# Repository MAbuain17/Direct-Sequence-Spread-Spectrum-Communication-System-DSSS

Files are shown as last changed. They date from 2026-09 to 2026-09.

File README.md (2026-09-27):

# DSSS Lab

**Configurable spread-spectrum hardware, receiver experiments and a multiuser CDMA study.**




The project combines a 2 MHz bench implementation with a configurable I/Q board design. Rev A integrates an STM32G474, dual DAC outputs, receive inputs and digital expansion around a programmable signal chain.

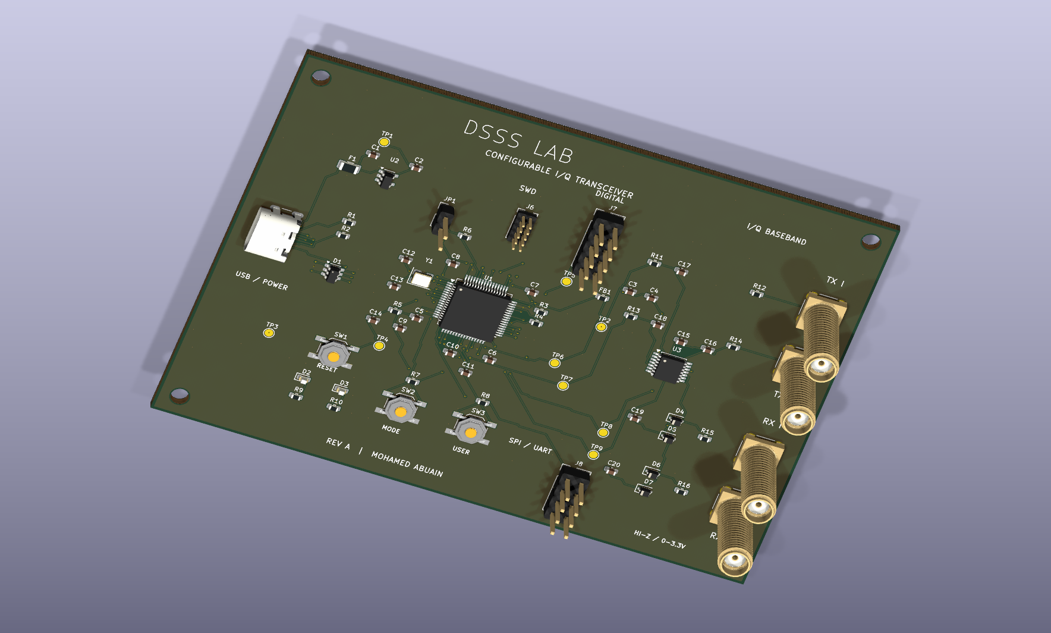
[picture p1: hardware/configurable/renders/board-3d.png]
Configurable DSSS transceiver PCB


## Configurable hardware — Rev A

| Area | Design |
|---|---|
| Data | User bits, text, hexadecimal payloads, PRBS and repeating patterns |
| Spreading | Selectable LFSR taps, seed, code phase and spreading length; uploaded sequences |
| Modulation | BPSK, QPSK, OOK and continuous-phase 2-FSK in the firmware specification |
| Analogue | Buffered TX I/Q, filtered and protected RX I/Q, four labelled SMA ports |
| Control | USB-C, reset/mode/user buttons, status LEDs and test points |
| Development | SWD/SWO programming, SPI/UART expansion, chip/data/PN/frame signals |
| PCB | 110 × 80 mm, four copper layers, routed nets, ground planes and M3 mounting holes |

The [hardware package](hardware/configurable/README.md) includes the schematic, routed PCB, board renders, component list and control interface.

## Explore the project

| Topic | Open |
|---|---|
| PCB architecture, BOM and renders | [Configurable hardware](hardware/configurable/README.md) |
| Signal modes and USB commands | [Control interface](hardware/configurable/control-interface.md) |
| Original bench build and captures | [Laboratory implementation](hardware/README.md) |
| BER, interference and synchronization | [Simulation results](docs/results.md) |
| Multiuser access, near–far and receiver algorithms | [CDMA extension](docs/cdma.md) |
| Interactive code and receiver study | [CDMA signal explorer](visualizer/index.html) |
| Signal-chain conventions and parameters | [Methodology](docs/methodology.md) |
| Python, MATLAB and Octave setup | [Getting started](docs/getting-started.md) |

## Run Python

From the repository root, using Python 3.10 or later:

```bash
python -m pip install -e .
python -m unittest discover -s tests -v
python examples/burst_link.py
python -m dsss_lab.experiments
python examples/pulse_shaping.py
python examples/cdma_study.py
```

For a smaller run, add `--quick` to the experiment command. CSV files, figures and environment metadata are written to `results/`. Running without installing is also possible with `PYTHONPATH=src` on Linux/macOS; see the Windows guide for PowerShell.

## Run MATLAB

No Communications Toolbox is required. From the repository root:

```matlab
addpath('matlab');
test_dsss;
run_experiments('results/matlab', 12000);
advanced_demo('results/matlab');
```

MATLAB shares deterministic test vectors with Python. Random-number streams differ, so Monte Carlo results should agree statistically, not bit-for-bit. **Python, GNU Octave and native MATLAB pass the published GitHub Actions validation workflows.** Native MATLAB runs automatically when its implementation, shared vectors or workflow changes and remains manually dispatchable.

## What the software explores

| Area | Implemented experiments |
|---|---|
| Data | Random bits, constants, alternating patterns, bursts, UTF-8 text, 8-bit PCM, CRC32 frames |
| Spreading | Exact hardware XNOR recurrence, code phase, autocorrelation, configurable spreading length, two-user Gold-family interference |
| Channels | AWGN; in-band and out-of-band tones; swept interference; burst noise; multipath; symbol-independent Rayleigh fading |
| Receiver | Coherent despreading, known-preamble delay/CFO acquisition, burst phase correction, known-channel matched combining |
| Front end | Carrier offset, phase offset/noise, fractional timing error, ADC clipping/quantization, IQ imbalance, RRC pulse shaping |
| Measurements | BER with Wilson intervals, frame CRC failure rate, acquisition success, raw decision EVM, Welch PSD and 99% occupied bandwidth |
| Coding | Soft repetition decoding with equal information-bit energy as a normalization check |

## BER and interference

DSSS and BPSK BER against theory

At equal information-bit energy, DSSS and ordinary coherent BPSK have the same theoretical BER in AWGN. Spreading's interference behaviour depends on the interferer's spectrum and the receiver. The experiments include cases where DSSS helps and cases where the narrower unspread receiver performs better.

Interference comparison

The simulation uses 60,000 bits per AWGN point and 30,000 bits per interference point. Source CSVs include error counts and confidence intervals; seeds and model settings are documented in [methodology](docs/methodology.md).

## From DSSS to CDMA

The [CDMA extension](docs/cdma.md) combines four spread-spectrum users in one channel and compares a matched filter, decorrelator and linear MMSE receiver under code-phase and near–far changes. The sweep records 45 conditions with 12,000 desired-user bits each. A separate [browser explorer](visualizer/index.html) exposes the code correlations, chip waveforms and receiver decisions interactively.

To use the explorer, download or clone the repository and open `visualizer/index.html` in a browser.

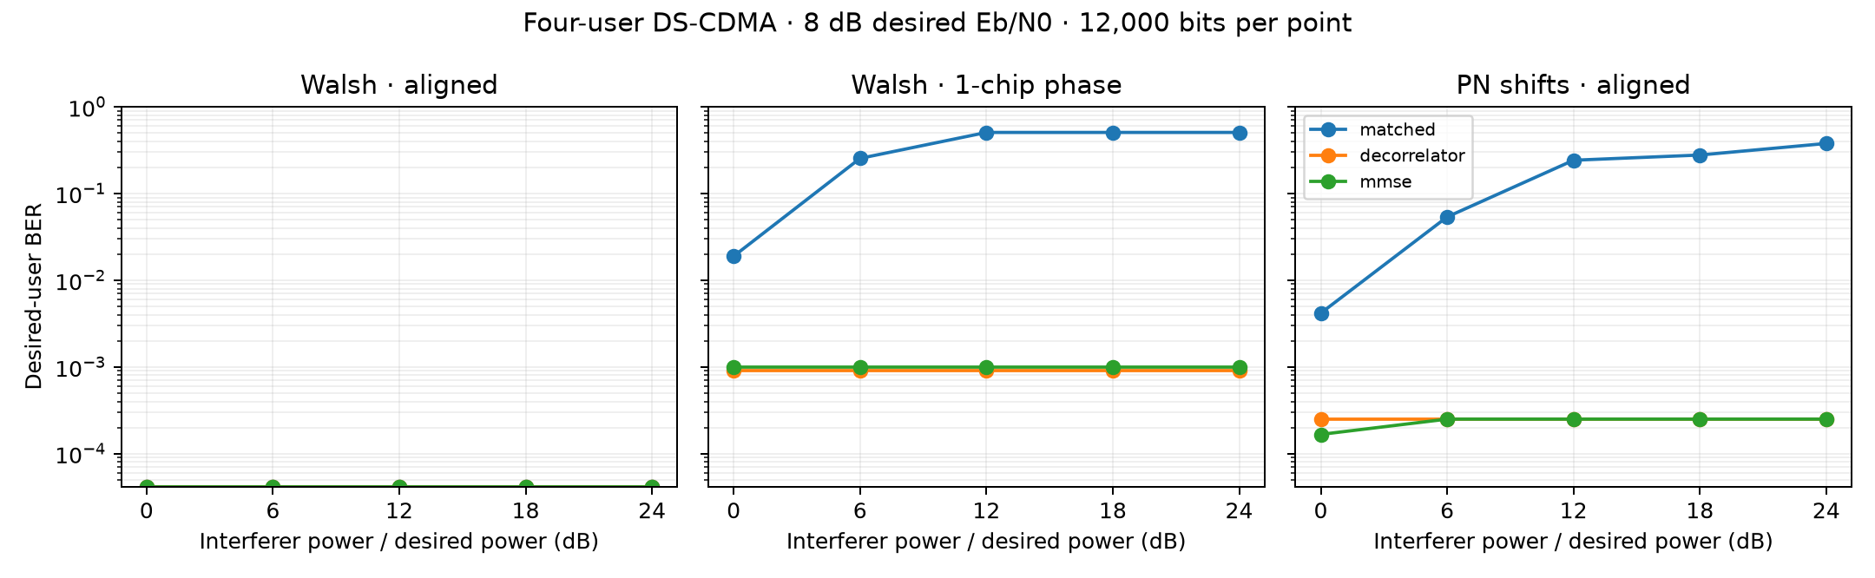
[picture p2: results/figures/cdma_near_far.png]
Four-user CDMA receiver comparison


## Credits

Project by **Mohamed Abuain**. The university bench implementation was supervised by Prof. Tammam Benmusa. Its circuit reference and source article are recorded in the [design references](docs/attribution.md).

[Software licence](LICENSE.md) · [Changelog](CHANGELOG.md) · [Roadmap](docs/roadmap.md)

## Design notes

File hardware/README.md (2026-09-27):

# Laboratory implementation

The original 2 MHz university bench project by Mohamed Abuain. The new [configurable Rev A board](configurable/README.md) adds a programmable signal chain and I/Q interfaces.

Breadboard assembly

The transmitter and receiver use PN generators, XOR spreading, square-carrier BPSK, comparator-driven code acquisition, a latch and clock switch, and an LM/MC1496 balanced demodulator. The laboratory setup uses a shared reference and a wired connection between transmitter and receiver.

## Circuit files

| File | Description |
|---|---|
| [DSSS_MAbuain.ms14](original/DSSS_MAbuain.ms14) | Main Multisim 14 project |
| [GOLD1.ms14](original/GOLD1.ms14) | Additional Multisim project |
| [MC1496_split_Gilbert_Cell_Test.asc](original/MC1496_split_Gilbert_Cell_Test.asc) | LTspice balanced-demodulator test schematic |
| `original/dsss.kicad_*` | Original KiCad layout concept |
| [Laboratory report](../docs/original-report.pdf) | Circuit description, measurements and discussion |

The [Rev A PCB package](configurable/README.md) contains the programmable baseband design, routed board and renders. [Engineering notes](../docs/errata.md) explain the original clock and spreading conventions.

## Laboratory captures

| Capture | Description |
|---|---|
| [Lab setup](../assets/lab-15.jpg) | Breadboard connected to test equipment |
| [Board close-up](../assets/lab-20.jpg) | Component placement and wiring |
| [Logic waveforms](../assets/lab-11.jpg) | Oscilloscope capture of digital signals |
| [Spectrum](../assets/lab-14.jpg) | Spectrum-analyzer capture |
| [Recovered signal](../assets/lab-01.jpg) | Demodulated waveform |

The report provides the context for these captures. Numerical BER and channel studies are documented in [simulation results](../docs/results.md).

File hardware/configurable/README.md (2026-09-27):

# Configurable DSSS transceiver — Rev A

Rev A PCB

A USB-controlled I/Q baseband board built around the STM32G474RET6. The architecture replaces fixed logic with programmable data generation, spreading and symbol mapping, while exposing both analogue channels and digital timing signals for measurement.

**Design:** 110 × 80 mm · four copper layers · 70 circuit components · four SMA ports · USB-C · SWD · SPI/UART expansion.

## Configurable signal chain

```mermaid
flowchart LR
    H[USB host: payload and configuration] --> P[Payload / preamble / CRC]
    P --> S[Programmable spreading]
    N[LFSR taps, seed, length and phase] --> S
    S --> M[BPSK / QPSK / OOK / 2-FSK mapping]
    M --> D[Timer-triggered dual DAC + DMA]
    D --> T[RC filters + I/Q buffers]
    T --> O[TX I / TX Q]
    I[RX I / RX Q] --> A[Input resistors, clamps and RC filters]
    A --> B[Receive buffers + dual ADC]
    B --> R[DMA capture / host analysis]
    S --> G[Chip clock / data / PN / frame header]
```

## Planned operating controls

| Control | Options |
|---|---|
| Payload | User bit string, hexadecimal bytes, UTF-8 text, PRBS, alternating bits, all-zero/all-one and repeating patterns |
| PN sequence | Configurable Fibonacci LFSR order, feedback taps, seed, code phase and spreading length; optional uploaded chip sequence |
| Modulation | BPSK, Gray-mapped QPSK, OOK and continuous-phase 2-FSK |
| Timing | Chip rate, samples per chip, burst duration, frame spacing and repeat count |
| Framing | Preamble, length, payload and CRC32; raw chip mode for scope captures |
| Experiments | I/Q loopback, code mismatch, delay sweeps, burst acquisition and known-pattern BER comparisons |
| Instrumentation | Digital chip clock, data, PN and frame signals; DAC/ADC test pads; status LEDs |

Rev A includes the schematic, routed PCB and control specification. Firmware and board bring-up are the next development stage. The Python/MATLAB simulations remain available for numerical experiments.

## Hardware blocks

| Block | Implementation |
|---|---|
| Processing | STM32G474RET6, LQFP64; Cortex-M4 with hardware timers, DMA, dual DAC and multiple ADCs |
| USB | GCT USB4105 USB-C connector, separate 5.1 kΩ CC pull-downs, USBLC6 protection and 22 Ω data-line resistors |
| Power | USB 5 V, 500 mA PTC, AP2112K 3.3 V regulator; ferrite-filtered analogue rail and local decoupling |
| Clock | 8 MHz crystal with load capacitors; USB clock configuration described in the firmware plan |
| Transmit | PA4/PA5 DAC outputs, 1 kΩ / 1 nF RC filters, TLV9064 unity-gain buffers and 100 Ω output isolation |
| Receive | Series input resistance, Schottky clamps, 1 kΩ / 1 nF RC filtering, TLV9064 buffers and PC0/PC1 ADC inputs |
| Development | SWD/SWO, reset button, boot jumper, mode/user buttons, TX/RX LEDs and SPI/UART header |
| Mechanical | Four M3 mounting holes, separated USB/power, processing and analogue regions, labelled SMA ports |

The SMA connections carry **DC-biased baseband I/Q**, with high-impedance loading. They are not antenna outputs or 50 Ω line drivers. The default development target is 25 kchip/s at four samples/chip; the analogue RC corner is approximately 159 kHz. Rate limits depend on firmware timing, conversion settings and filter response.

## Design files

| File | Contents |
|---|---|
| [KiCad project](dsss-configurable.kicad_pro) | Board rules and project settings |
| [Schematic](dsss-configurable.kicad_sch) | Connected component-level design |
| [PCB](dsss-configurable.kicad_pcb) | Four-layer layout, copper tracks, vias and filled ground planes |
| [Local symbol library](dsss-configurable.kicad_sym) | Embedded component symbols for the project |
| [Schematic preview](renders/schematic.svg) | Browser-readable circuit drawing |
| [Top view](renders/board-top.png) | Component placement and silkscreen |
| [Copper view](renders/copper.svg) | Routed layout |
| [Bill of materials](bom.csv) | References, values and footprints |
| [Pin map](pin-map.md) | MCU peripheral and connector assignments |
| [Control interface](control-interface.md) | Proposed USB commands, modes and frame format |
| [Design review](design-review.md) | Connectivity checks and next review items |

Open `dsss-configurable.kicad_pro` in KiCad 10. The standard footprint and 3D model libraries supply the component geometry; the local symbol library is included in the project.

## Component references

- [ST STM32G474RE datasheet](https://www.st.com/resource/en/datasheet/stm32g474re.pdf)
- [TI TLV9064](https://www.ti.com/product/TLV9064)
- [Diodes AP2112 datasheet](https://www.diodes.com/datasheet/download/AP2112.pdf)

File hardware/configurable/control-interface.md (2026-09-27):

# USB control and firmware plan

This document specifies the Rev A firmware interface. It is a design specification; no flashed-board execution is recorded.

## Commands

USB CDC carries one JSON command per line. Replies include the command name, success/error status and the active configuration. The board starts idle after reset and applies configuration changes between bursts.

| Command | Purpose |
|---|---|
| `configure` | Set modulation, chip rate, samples/chip, spreading length and amplitude |
| `pn` | Set LFSR order, taps, nonzero seed and phase, or upload a custom binary chip sequence |
| `payload` | Upload a bit string, hexadecimal bytes or UTF-8 text; select a repeating test pattern |
| `frame` | Set preamble, CRC, repeat count and inter-frame gap |
| `tx` | Start or stop transmission; report samples and frames sent |
| `capture` | Return a bounded dual-ADC capture with sample rate and channel metadata |
| `status` | Return configuration, DMA underruns/overruns and frame counters |
| `loopback` | Compare a known transmitted pattern with captured I/Q after host synchronization |

Example configuration:

```json
{"command":"configure","modulation":"qpsk","chip_rate_hz":25000,"samples_per_chip":4,"spreading_length":127,"amplitude":0.6}
{"command":"pn","order":7,"taps":[7,6],"seed":1,"phase":0}
{"command":"payload","encoding":"bits","data":"1011001010110001"}
{"command":"tx","action":"start","frames":100}
```

The taps use polynomial exponents: `[7,6]` represents x⁷ + x⁶ + 1. Firmware must define the shift direction and output stage, and publish sequence vectors before comparing this mode with the existing inverted-feedback model. Arbitrary taps can produce short cycles; only verified maximal polynomials should be labelled PRBS.

## Modes

| Mode | Mapping | I/Q outputs |
|---|---|---|
| BPSK | Chip 0 → +1; chip 1 → −1 | I carries the bipolar chip waveform; Q stays at the bias level |
| QPSK | Gray mapping: 00 → (+,+), 01 → (+,−), 11 → (−,−), 10 → (−,+), normalized by √2 | Consecutive spread-chip pairs drive I and Q |
| OOK | Chip 0 → off; chip 1 → on | I carries the unipolar waveform; Q stays at bias |
| 2-FSK | Chip chooses f₀ or f₁; phase accumulator continues across chip boundaries | I/Q carry the complex baseband oscillator |

Digital symbols are converted to unsigned DAC samples around a mid-supply bias. Requested amplitude must leave buffer and DAC headroom. Chip rate counts spread chips before QPSK pairing; QPSK symbol rate is half the chip rate. An odd chip count is padded explicitly and its original length retained.

## Frame format

`preamble | payload length | payload | CRC32`

The preamble, length endianness and CRC polynomial/initialization belong in shared golden vectors. Raw mode bypasses framing for continuous code and logic measurements. A repeating payload is useful for eye diagrams; a PRBS payload is useful for error-rate tests.

## Firmware structure

1. Configure clocks, USB CDC, SWD, GPIO and the analogue peripherals. Use HSI48 with USB SOF clock recovery for USB; configure the HSE/PLL separately for processing and timers.
2. Generate payload bits, PN chips and mapped symbols into bounded ping-pong buffers. Use DMA to stream packed dual-DAC samples under a shared timer trigger.
3. Configure ADC1/ADC2 with simultaneous sampling, timer triggering and DMA. Confirm trigger routing and sampling-time settings against the STM32G4 reference manual.
4. Use the digital header for chip/data/PN/frame observations. Keep the GPIO waveform schedule synchronized with the sample timer.
5. Detect underruns and overruns, stop cleanly on error, and apply configuration changes at buffer or frame boundaries.
6. Implement a host receiver for correlation, code-phase search, symbol decisions and CRC/BER comparison. Later move selected receiver stages onto the MCU after profiling.

Initial analogue target: 25 kchip/s, four samples/chip, 100 ksample/s per DAC channel. Buffer memory, USB throughput, ADC capture bandwidth and interrupt load determine higher-rate operation.

## Useful extensions

- Uploaded PN sequences and Gold-code pairs for code-division experiments.
- Adjustable gain/phase mismatch in the transmitted I/Q waveform.
- Repeated frames with controlled code phase for acquisition sweeps.
- SPI-connected display, RF conversion module or programmable attenuator.
- Code and modulation profiles stored in flash with a configuration checksum.

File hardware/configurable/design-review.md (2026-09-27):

# Rev A design review

## CAD checks

KiCad 10.0.6 checks on 27 September 2026:

| Check | Result |
|---|---|
| Schematic ERC | 0 violations |
| PCB DRC | 0 violations |
| Unconnected PCB items | 0 |
| Layout | Four copper layers; 110 × 80 mm |
| Circuit components / nets | 70 / 48 |

The schematic and PCB use the same component pin map. The USB connector shell is grounded, unused MCU pins are marked unconnected, and the inner ground plane connects the analogue and digital return paths. Local ground pours also cover the outer copper layers.

Default signal clearance is 0.15 mm. Escape vias use 0.45 mm pads and 0.20 mm drills. The USB-C footprint has a specific 0.18 mm pad-to-locating-hole clearance rule to accommodate its standard library geometry; confirm that geometry and tolerances with the board supplier.

Machine-readable counts are recorded in [design-checks.json](design-checks.json).

## Engineering review before a prototype

- Confirm the ordered MCU, regulator, USB connector, crystal and SMA part numbers against their footprints and data sheets.
- Review USB D+/D− routing, return continuity and signal integrity at full-speed USB; the existing traces are connected but do not constitute an impedance-controlled transmission-line specification.
- Check USB current budget, AP2112 thermal dissipation, PTC hold current, ferrite current rating and analogue-rail noise.
- Confirm the crystal load and drive settings. The 15 pF capacitor choice assumes approximately 2.5 pF total stray capacitance for a 10 pF load target; adjust for the selected crystal and board.
- Check DAC output headroom, buffer stability, input clamp leakage and the RC response at each intended sample/chip rate.
- Verify boot/reset options, USB clock recovery, timer trigger selection, dual-ADC sampling and DMA buffer timing in firmware.
- Review layer stack-up, minimum drill capability, annular rings, assembly access and connector mechanical fit with the manufacturer.

## Development stage

Rev A is a connected schematic and routed PCB design. Firmware implementation, fabrication and physical measurements are subsequent milestones. The existing laboratory photographs document the earlier bench implementation.

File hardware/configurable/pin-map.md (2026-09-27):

# Pin map

## STM32G474RET6 — LQFP64

| Function | Pin / port | Board net |
|---|---|---|
| TX I | 18 / PA4, DAC1_OUT1 | DAC_I |
| TX Q | 19 / PA5, DAC1_OUT2 | DAC_Q |
| RX I | 8 / PC0, ADC1_IN6 | ADC_I |
| RX Q | 9 / PC1, ADC2_IN7 | ADC_Q |
| USB D− / D+ | 45 / PA11, 46 / PA12 | USB_DM_MCU / USB_DP_MCU |
| HSE crystal | 5 / PF0, 6 / PF1 | HSE_IN / HSE_OUT |
| Reset | 7 / PG10-NRST | NRST |
| Debug | 49 / PA13, 50 / PA14, 56 / PB3 | SWDIO / SWCLK / SWO |
| Chip clock | 42 / PA8 | CHIP_CLK |
| Data / PN | 59 / PB6, 60 / PB7 | DATA_OUT / PN_OUT |
| Frame marker | 38 / PC6 | FRAME |
| SPI2 | 34 / PB12, 35 / PB13, 36 / PB14, 37 / PB15 | SPI_CS / SPI_SCK / SPI_MISO / SPI_MOSI |
| USART2 | 14 / PA2, 17 / PA3 | UART_TX / UART_RX |
| Buttons | 2 / PC13, 3 / PC14 | BTN_MODE / BTN_USER |
| Indicators | 24 / PB0, 25 / PB1 | LED_TX / LED_RX |
| Boot selection | 61 / PB8-BOOT0 | BOOT0 |

The pin assignments are based on the [ST datasheet](https://www.st.com/resource/en/datasheet/stm32g474re.pdf). Firmware must configure alternate functions and the boot option bytes for the selected usage.

## Connectors

| Connector | Odd pins | Even pins |
|---|---|---|
| J6 SWD, 2 × 5 at 1.27 mm | 1: 3.3 V; 3: GND; 5: GND; 7: unused; 9: GND | 2: SWDIO; 4: SWCLK; 6: SWO; 8: unused; 10: NRST |
| J7 digital, 2 × 5 at 2.54 mm | 1: 3.3 V; 3: chip clock; 5: data; 7: PN; 9: frame | Ground on all even pins |
| J8 expansion, 2 × 4 at 2.54 mm | 1: 3.3 V; 3: SPI CS; 5: MOSI; 7: UART TX | 2: GND; 4: SPI SCK; 6: MISO; 8: UART RX |

J2/J3 are TX I/Q; J4/J5 are RX I/Q. All SMA shells connect to ground. JP1 connects BOOT0 to 3.3 V; R6 holds it low with the jumper removed.

All digital expansion signals use 3.3 V logic. The USB port is the board's power input.

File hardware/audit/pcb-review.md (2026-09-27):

# PCB review and layout plan

The KiCad files contain a component placement study with routing pending. The structural audit records 169 footprints, 532 pads, 112 pads assigned a nonzero net, 26 declared nets, two zones, zero track segments, and zero vias. The supplied schematic contains 10 placed symbols and zero wires. These counts are reproduced by `python tools/audit_kicad.py` and recorded in `structural-audit.json`.

ERC and DRC are pending completion of the connected schematic and board layout.

## Electrical issues to resolve before layout

| Area | Required work | Acceptance evidence |
|---|---|---|
| Source of truth | Export the as-built Multisim netlist and compare it with the report and QEX schematic | Pin-by-pin reviewed netlist and reconciled BOM |
| Logic families | Audit LS outputs into HC and 4000-series CMOS, including the comparator | Worst-case VOH/VOL versus VIH/VIL and fanout worksheet; validated substitutions |
| PN generator | Confirm QA/QG taps, inversion, reset, unused eighth output and feedback pin assignment | 127-state capture and reset test |
| Clock doubler | Check RC timing, pulse widths, hysteresis and frequency over supply/tolerance | Minimum high/low pulse margins for the selected receiving IC |
| Clock switching | Check CD4066 pulse integrity and avoid runt pulses while switching 4/2 MHz | Clock capture through acquisition and repeated resets |
| Comparator/latch | Confirm unused comparator input pair, enable pin, polarity and startup state | Deliberately varied initial code phases and verified lock |
| Demodulator | Validate exact MC/LM1496 manufacturer pinout, bias, input attenuation and load | DC operating points, gain and clipping measurements |
| Power | Separate labelled +5 V logic and +12 V analogue inputs with common reference | Current limits, local decoupling, startup/reset behaviour |
| Output conditioning | Design/verify low-pass filtering and logic threshold recovery | Recovered waveform, duty distortion and BER under a defined test |
| Testability | Add labelled probes for reference, carrier, TX PN, RX PN, spread data, lock and recovered data | Accessible ground-return pairs and test-point map |

Check LS-to-HC input margins against the selected parts' data sheets; consider HCT where TTL-compatible thresholds are needed. Verify the 74LS04 feedback network's pulse widths and hysteresis across supply and component tolerances.

## Proposed physical organization

Use one board with clearly separated reference/divider, transmitter, acquisition and demodulator regions. Put external connections at the edges and the analogue demodulator away from the clock doubler. Keep a continuous ground reference, short clock paths, local decoupling at every IC, mounting holes, legible pin-one marks and measurement points with adjacent grounds. Footprints must match the verified BOM, including the actual demodulator package.

Select the layer count, trace widths, connectors, supplies and mounting dimensions after verifying the netlist and equipment interface. Rebuild placement from the completed schematic and remove unused footprints.

## Build sequence

1. Complete and review the schematic and BOM, including power and unused pins.
2. Run ERC with documented, justified exclusions; validate timing and analogue bias.
3. Place and route the board from that schematic; run DRC with zero unexplained violations and zero unrouted nets.
4. Inspect copper, return paths, clearances, drill sizes, silkscreen and 3D fit; independently compare netlist and board.
5. Generate fabrication files only after those checks, then build and measure a prototype to validate the board.

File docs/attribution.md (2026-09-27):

# Design references

The circuit is based on André Kesteloot, N4ICK, “Experimenting With Direct-Sequence Spread Spectrum,” *QEX*, December 1986, pp. 5–9, published by ARRL. The [complete issue](QEX_1986_12.pdf) is included for reference; the article begins on printed page 5.

Mohamed Abuain completed the university implementation individually: Multisim circuit simulation, breadboard assembly, waveform and spectrum measurements, and the [laboratory report](original-report.pdf). The report acknowledges supervision by Prof. Tammam Benmusa.

## Circuit adaptations

The QEX circuit compares seven-bit words with XOR/OR/NAND gates. The university report and schematic use a 74HC688 comparator and a laboratory function generator for the 4 MHz reference.

The hardware files include Multisim projects, an LTspice demodulator schematic and a KiCad placement study. The Python and MATLAB models implement the PN recurrence and extend the experiments to BER, interference, acquisition and receiver impairments. See the [implementation overview](implementation-matrix.md) for feature coverage.

## References

- [QEX source metadata](qex-source.json)
- [Engineering notes on the report](errata.md)
- [TI SN74LS164](https://www.ti.com/product/SN74LS164): shift-register specifications
- [TI SN74HC688](https://www.ti.com/product/SN74HC688): comparator specifications

## Configurable Rev A architecture

The [Rev A board](../hardware/configurable/README.md) uses a programmable STM32G474 signal chain, USB control and buffered I/Q interfaces. Its component references, peripheral assignments and control specification are recorded with the PCB project.

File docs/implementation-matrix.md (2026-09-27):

# Implementation overview

This repository follows one signal chain from a laboratory spread-spectrum transceiver through a configurable board design to reproducible receiver experiments.

| Layer | Engineering work | Explore |
|---|---|---|
| Laboratory transceiver | 2 MHz carrier and chip clock, seven-stage PN generation, logic spreading, analogue demodulation, clock alignment and recovered data captures | [Build photographs and waveforms](../hardware/README.md) |
| Configurable Rev A | Four-layer routed PCB with an STM32G474, USB control, dual I/Q DAC outputs, protected I/Q inputs, SWD, expansion and front-panel controls | [Schematic, board renders, BOM and interface](../hardware/configurable/README.md) |
| DSSS modelling | Exact PN recurrence, energy-normalized BPSK, packet framing, acquisition, pulse shaping, interference, fading and front-end impairments | [Methods](methodology.md) · [Results](results.md) |
| CDMA extension | Code families, four-user composite waveform, chip-phase and near–far sweeps, matched/decorrelating/MMSE receivers and desired-user BER | [Architecture and results](cdma.md) |
| Interactive study | Browser-based exploration of code correlation, near–far loading and multiuser receiver decisions | [CDMA explorer](../visualizer/index.html) |

The MATLAB and Python implementations share deterministic test vectors. Their random streams are independent; numerical sweeps are compared by conditions and statistics rather than sample identity. The [validation workflow](../.github/workflows/validate.yml) runs the Python suite and Octave experiments; the separate [MATLAB workflow](../.github/workflows/matlab.yml) validates the native MATLAB path.

The original bench circuit, Rev A PCB and simulation models are different engineering stages. The [hardware page](../hardware/README.md) contains the bench record, while the [Rev A page](../hardware/configurable/README.md) contains its circuit and layout package.

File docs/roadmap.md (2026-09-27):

# Maintenance and research roadmap

Version 0.1 includes the communications models, laboratory files and automated tests. Python, GNU Octave and native MATLAB first passed their published GitHub Actions workflows on 21 September 2026. Native MATLAB reruns on relevant MATLAB/vector changes and remains manually dispatchable.

| Priority | Work item | Milestone |
|---|---|---|
| P0 | Rev A firmware | USB command parser, configuration validation, shared PN/mapping vectors, timer/DMA DAC streaming |
| P0 | Rev A electrical review | Clock, USB, regulator thermals, analogue range and sampling requirements checked against selected parts |
| P1 | Board bring-up | Power rails, SWD, USB enumeration, DAC test tones and ADC captures |
| P1 | Configurable payload and PN | User bits/text/patterns, LFSR taps/seed/phase and uploaded codes |
| P1 | Modulation profiles | BPSK, QPSK, OOK and 2-FSK captures against known sample vectors |
| P2 | Loopback receiver | Correlation, code-phase estimation, timing alignment, CRC and BER comparison |
| P2 | CDMA model extensions | Asynchronous symbol arrivals, multipath channel estimation and measured near–far captures |
| P2 | RF expansion | SPI-controlled conversion/attenuation module after validating baseband interfaces |

Each extension should specify its channel assumptions, comparison baseline and acceptance tests.

## Contribution workflow

Use focused branches and descriptive commits. Record instrument settings and raw samples with new measurements. When changing numerical code, run the unit suite and relevant experiments, then review the generated CSVs and figures.

Planned tasks are listed in [issue-backlog.json](issue-backlog.json). GitHub Actions runs the validation suite on code changes.

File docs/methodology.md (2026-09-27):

# Model and measurement conventions

## Two different models

The **hardware logic model** uses a continuous 127-chip PN stream, a 2 MHz square carrier, and ideal XOR operations. With 1,000 chips per data-clock interval, an interval lasts 500 microseconds. That configuration models a 2 kHz data clock. The original board can instead select a direct 2 kHz square-wave test input: each high or low interval then lasts 250 microseconds, or 500 chips. These are different experiments.

The **communications model** resets a selected spreading code at each bit. Its default length is 127 chips and its reference chip rate is 2 Mchip/s, giving 15,748.03 bit/s when a physical rate is needed. This choice makes the baseline experiments easy to interpret; it does not reproduce the hardware's 1,000-chip clock interval. Both models use the same documented feedback recurrence.

## PN recurrence

Represent the active seven-stage state as an integer `s`, with QA in bit 6 and QG in bit 0. Before each update, the exported bit is QA. Compute:

```python
feedback = 1 ^ ((s >> 6) & 1) ^ (s & 1)
s = (s >> 1) | (feedback << 6)
```

This yields the report's initial states `0, 64, 32, 80, 40, 84, 42, 85`. The all-zero reset is allowed; the all-one state is a fixed point and is rejected. The period is 127. QA contains 63 ones and 64 zeros over the period. With bipolar values, periodic normalized autocorrelation is 1 at zero lag and −1/127 elsewhere. The schematic's serial feedback node gives a cyclically shifted version of this sequence; exporting QA does not assert pin-level timing equivalence.

A requested spreading length other than 127 truncates or repeats this sequence. It is **not** a new maximal-length sequence and must not be described as one. Code length, PN period and chips per data bit are separate quantities.

## Energy and AWGN

Bit mapping is `0 -> +1`, `1 -> -1`. For spreading length L and S samples per chip, the rectangular waveform has amplitude `1/sqrt(L*S)`, so its discrete energy per uncoded bit is exactly one. Samples represent an orthonormal discrete-time model, not calibrated voltage or watts at a specified impedance.

Complex AWGN has variance N0/2 in each quadrature, with `N0 = 10**(-EbN0_dB/10)`. The receiver integrates against the unit-energy spreading pulse. For ideal coherent BPSK:

\[
P_b = \tfrac12\operatorname{erfc}\!\left(\sqrt{E_b/N_0}\right).
\]

The unspread baseline uses an all-one pulse over the same L*S samples. Consequently bit rate, sampling rate, bit energy and noise normalization are matched. Spreading does not provide AWGN coding gain. The repetition-code experiment allocates energy 1/3 to each of three copies; it changes time/throughput and checks energy normalization across coding rates.

## Interference cases

J/S is the mean injected interference power divided by mean desired signal power over the record. Burst duty is 10%; its average power is normalized after gating, so its instantaneous active power is higher. No transmit-power advantage is given to either receiver.

| Case | Frequency in cycles/sample | Interpretation at 2 Msamples/s |
|---|---|---|
| tone_inband | 0.001 | 2 kHz, inside the narrow unspread main lobe |
| tone_outofband | 0.037 | 74 kHz, outside that main lobe, within the DSSS band |
| chirp | Linear sweep −0.01 to +0.01 across each record/batch | −20 kHz to +20 kHz |
| burst | Complex white noise, 100 samples active per 1,000 | Wideband impulsive interference |

Python's BER runner processes 2,000-bit batches and draws a new interference phase per batch. MATLAB uses a single record per point; chirp duration and random streams therefore differ. These experiments compare the specified interference waveforms. A short deterministic PN code has spectral structure, so a single tone is not sufficient to estimate a general processing gain.

## Synchronization

The hardware logic trace assumes code lock. The original hardware acquisition circuit is not gate-delay simulated in Python.

The advanced receiver uses a known random 16-bit preamble spread over 127 chips/bit. It searches integer delays 0–64 samples and CFO candidates −0.0002, 0 and +0.0002 cycles/sample using complex correlation, then estimates phase. At a 2 MHz sample rate this CFO grid is −400, 0 and +400 Hz. The acquisition experiment reports joint delay/CFO success across repeated trials. The burst example corrects those estimates and checks a CRC-protected text payload.

The CFO trials are **on-grid**, the frame length is known, and there is no unknown-signal detector or false-alarm threshold. There is no fractional timing recovery, sample-clock tracking loop, Costas loop or Doppler tracker. Sensitivity plots with uncorrected CFO/phase explicitly use an uncompensated receiver.

## Multipath, fading and front-end models

Multipath impulse responses have unit total energy. The matched-channel combiner uses exact known taps and delays, so it is an idealized RAKE-equivalent bound without channel-estimation error. It does not remove all intersymbol interference. Rayleigh fading is independent per symbol with perfect complex receiver CSI; there is no correlated Doppler model.

Fractional delay uses linear interpolation and zero-filled boundaries. This approximation attenuates high-frequency samples; it is not a bandlimited fractional-delay filter. IQ imbalance is applied after rotating the BPSK signal by 45 degrees so the Q path is exercised; nominal rotation is undone afterward. ADC quantization clips each quadrature independently to ±0.5 before uniform quantization. Noise is added before quantization. Phase noise is a discrete Wiener phase process, not a measured oscillator spectrum.

RRC pulses have unit tap energy, 10-chip span and four samples per chip. Matched filtering compensates both filter group delays. Finite pulse truncation leaves residual ISI. 99% occupied bandwidth uses equal-tail cumulative Welch PSD power; it is not the report's manually estimated ~80% bandwidth.

## Statistics and reproducibility

BER CSVs include counts and 95% Wilson score intervals. Intervals describe finite-sample binomial uncertainty; correlated interference can violate independence and make those intervals optimistic. Frame results are CRC failure fractions, not an undetected-error guarantee. Raw RMS EVM compares complex decisions directly with ideal ±1 symbols, without fitted gain or phase correction.

The full Python run records the main seed and environment in `results/run_metadata.json`. The separate pulse-shaping example uses seed 99; the framed-burst example uses seed 7. Shared golden samples test exact deterministic receiver agreement across languages; equal numeric RNG seeds do not yield equal MATLAB and NumPy noise streams.

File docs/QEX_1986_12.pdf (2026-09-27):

is
58

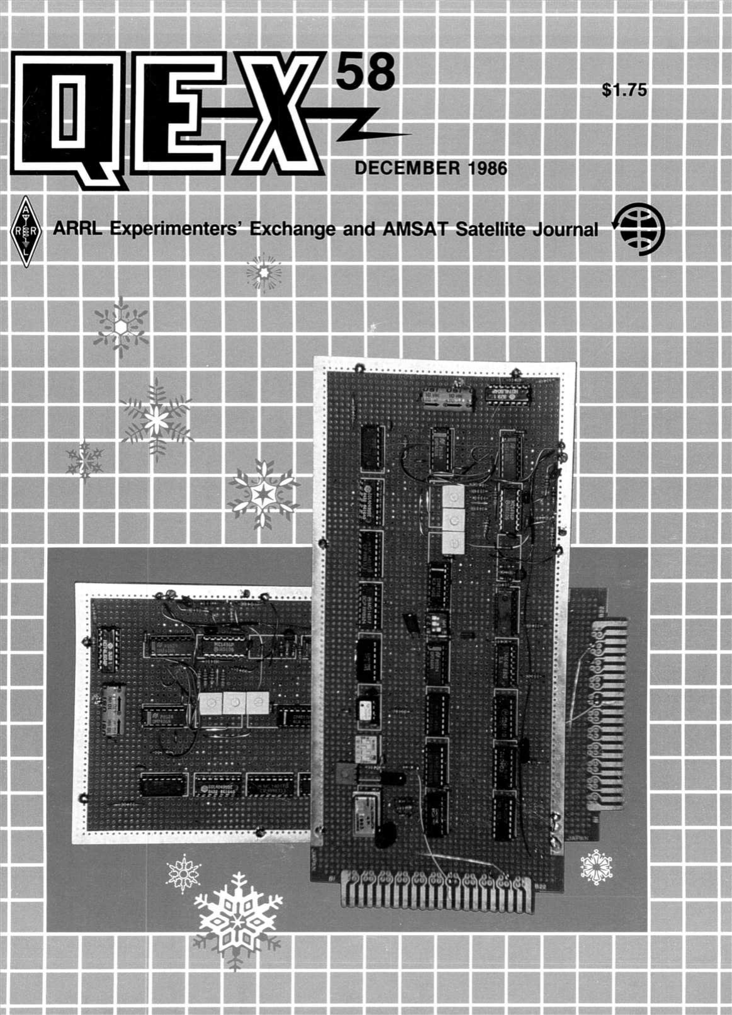
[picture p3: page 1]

1 r """N
i

# $1 .75 'so 0 DECEMBER 1986

4

## ARRL Experimenters Exchange and AMSAT Satellite Journal

# OjI E

i •

uW .a-f. Ky; V'T a'~Y a~'s

a

t. .
ou

ea• , a4.ab . aHA

,enonA

~.o
- | fat | i $ a aa.eteG -pupa o~ u •uaaa •i •a a .aoear •a

•a ril

i
. 0

'Gv GCa atl ~ •
usvae .. . .++aaO+T •, ~ • . e ++J

a+a+
+ ayi
I • ,F+
L 4 . + t + r i

!-

# _ ttf4_

∎

∎

∎

0' 0-

∎∎∎∎∎∎∎∎∎∎∎∎∎∎∎∎∎∎∎
∎∎

1

| 1 | //I•I•I•
∎∎
I | --oak | 4•000∎
∎∎

### I .__ =7311111111

∎∎

1 | --Emir | 1s~:aIIIIII
∎m-

1,- -1- -i

| | •uui
∎//∎Ot~f-/ | | ∎
QEX (ISSN : 0886-8093) is published monthly by the American Radio Relay League, Newington,
CT USA .
David Sumner, K1ZZ
Publisher
Paul L . Rinaldo, W4RI
Editor
Maureen Thompson, KA1DYZ
Assistant Editor
Dr . Ron Long, W8GUS
Associate Editor
William Conwell, K2PO
Geoffrey H . Krauss, WA2GFP Bill Olson, W3HOT
Contributing Editors
Lisa Fuini
QEX Circulation
Michelle Chrisjohn, WB1ENT Production Supervisor
Deborah Strzeszkowski
Assistant Production Supervisor Leslie Bartoloth
Typesetting and Layout
Sue Fagan
Graphic Design Supervisor
David Pingree
Technical Illustrator
Lee Aurick, W1SE
Advertising Manager
Sandy Gerli, AC1Y
Deputy Advertising Manager Technical Department
Charles L . Hutchinson, K8CH Manager
Gerald L. Hall, K1TD
Deputy Manager
Paul Pagel, N1FB, Mark Wilson, AA2Z Senior Assistant Technical Editors Bruce O . Williams, WA6IVC Assistant Technical Editor
Production Department
E . Laird Campbell, W1CUT, Manager Joel P . Kleinman, N1BKE, Deputy Manager Circulation Department
Debra Chapor, Manager
Offices
225 Main St, Newington, CT 06111 USA Telephone : 203-666-1541
Telex : 650215-5052 MCI
Electronic Mail : MC I MAIL ID :215-5052 (user name ARRL)
Subscription rate for 12 issues :
In the US by Third Class Mail :
ARRL/AMSAT Member $6, nonmember $12; US by First Class Mail :
ARRL/AMSAT Member $11, nonmember $17 ; Elsewhere by Airmail :
ARRL/AMSAT Member $21, nonmember $27 . QEX subscription orders, changes of address, and reports of missing or damaged copies may be marked : QEX Circulation . Members are asked to include their membership control number or a label from their QST wrapper when applying .
Copyright

1986 by the American Radio Relay League
Inc . Material may be excerpted from QEX without prior
permission provided that the original contributor is
credited, and QEX is identified as the source .

# TABLE OF CONTENTS

HF PACKET: COMMENTS AND TIPS

4
By Gregory P . Latta, AA8V
A major problem confronts the HF packet airwaves-too many data retries . Here's useful and practical information to help minimize this form of QRM and make packet operation enjoyable .
EXPERIMENTING WITH DIRECT-SEQUENCE SPREAD SPECTRUM

55
By Andre Kesteloot, N4ICK
This circuit transmits and receives spread-spectrum data, tests square waves and Morse code signals . It also uses a local TV or radio transmitter signal as an external reference
and employs equipment readily available to the radio
amateur .

A TWO-TONE GENERATOR WITH VERY LOW DISTORTION - 10 By George Pelissier, F1BBI
Check the linearity of your SSB transmitter with this 900- and
1200-Hz signal generator . A schematic and circuit description
is included . XEROX 820-1 COMPENDIUM-PART 5

12
By Dave Borden, K8MMO
From the Xerox 820-1 board to Fred to a Yaesu FT-7 HF transceiver : an interface that allows high-speed frequency hopping . PACANSWR may be packet radio's equivalent of the telephone answering machine .

# COLUMNS

CORRESPONDENCE
Learn about an update on inductance and capacitance magnification, how to obtain a velocity measuring device and find out why new hardware runs old software .

>50
By Bill Olson, W3HOT
Four basic components are necessary to test a VHF or UHF antenna . Here is practical information on using each part of the antenna measuring system .

~ll

L 58
'aa

### ABOUT THE COVER

On June 1, 1986, the FCC granted Amateur Radio operators authorization to use the spread-spectrum mode for communication . This is one of the experimental direct-sequence spread-spectrum circuit boards. See page 5 for complete circuit information .

December 1986

3

14

1

### THE AMERICAN RADIO RELAY LEAGUE, INC

The American Radio Relay League, Inc,
is a noncommercial association of radio amateurs, organized for the promotion of
interest in Amateur Radio communication and experimentation, for the establishment of networks to provide communications in the event of disasters or other emergencies, for the advancement of the radio art and of the public welfare, for the representation of the radio amateur in legislative matters, and for the maintenance of fraternalism and a high standard of conduct .
ARRL is an incorporated association without capital stock chartered under the laws of the State of Connecticut, and is an exempt organization under Section 501(c)(3) of the Internal Revenue Code of 1954 . Its affairs are governed by a Board of Directors, whose voting members are elected every two years by the general membership. The officers are elected or appointed by the Directors . The League is noncommercial, and no one who could gain financially from the shaping of its affairs is eligible for membership on its Board .
"Of, by, and for the radio amateur," ARRL numbers within its ranks the vast majority of active amateurs in the nation and has a proud history of achievement as the standard-bearer in amateur affairs . As its membership journal, ARRL publishes QST monthly .
A bona fide interest in Amateur Radio is the only essential qualification of membership; an Amateur Radio license is not a prerequisite, although full voting membership is granted only to licensed amateurs in the US and Canada .

Officers
President: LARRY E . PRICE, W4RA
PO Box 2067, Statesboro, GA 30458
Executive Vice President : DAVID SUMNER, K1ZZ

### AMSAT

RADIO AMATEUR SATELLITE CORP C~

President: VERN "RIP" RIPORTELLA, WA2LQQ

Purposes of QEX :
1) provide a medium for the exchange of ideas and information between Amateur Radio experimenters
2) document advanced technical work in the Amateur Radio Field
3) support efforts to advance the state of the Amateur Radio art .

All correspondence concerning QEX should be addressed to the American Radio Relay League, 225 Main Street, Newington, CT USA 06111 . Envelopes containing manuscripts and correspondence for publication in QEX should be marked: Editor, QEX.
Both theoretical and practical technical articles are welcomed . Manuscripts should be typed and double spaced . Please use the standard ARRL abbreviations found in the 1985 and 1986 ARRL Handbooks and in the January 1984 issue of QST. Photos should be glossy, black-and-white positive prints of good definition and contrast, and should be the same size or larger than the size that is to
appear in QEX.
Any opinions expressed in QEX are those of the authors, not necessarily those of the editor or the League . While we attempt to ensure that all articles are technically valid, authors are expected to defend their own material . Products mentioned in the text are included for your information ; no endorsement is implied. The information is believed to be correct, but readers are cautioned to verify availability of the product before sending money to the vendor .
2 | QEX
I | I
r | I

I

1 I

# Space Symposium

There is an electric feeling in the air when a group of high techies meet to talk about their projects . That certainly happened at the AMSAT-sponsored Amateur Radio space symposium held over the November 7-9 weekend in Dallas . Many came to tell others about their current work and that of the past year. Jan King, W3GEY, was there to talk about 1990 and beyond; his subject : Phase 4-a proposed geostationary satellite system .
Jan recently completed an engineering study for Phase 4 . He concluded that the next step into space for the Amateur Satellite Service should be satellites that stay put and can be used on a regular schedule. Also, if Phase 4 were to serve only the experimenters and weak-signal VHFers (OSCAR satellites' traditional user base), then funding sources would be insufficient to boost the dollars into the 2 or 3 million dollar range needed . This order of magnitude of funding is needed to pay for the construction and launching of a more-massive spacecraft than previously tried by AMSAT . For a satellite to stay in geostationary orbit, a propulsion system and fuel are needed for station keeping . To have the signal go 22,300 miles and arrive on the ground with good signal strength, the transmitted power needs to be about 10 dB higher than that of OSCAR 10. A larger electrical power source is thus required .
A geostationary orbit and better signal make Phase 4 useful for public-service applications . It is from this realm that Jan expects to find the interest that will generate the additional funding needed . Public-service communications is permitted in the United States under FCC rules for the Amateur Radio Service . We have developed various forms, such as disaster communications, Amateur Radio in the classroom, and routine third-party message relay. According to the ITU Radio Regulations :
"2733 (2) It is absolutely forbidden for amateur stations to be used for transmitting
international communications on behalf of third
parties .
"2734 (3) The preceding provisions

# in Dallas

# i ng

may be modified by
special arrangements
between the administrations of the countries
concerned ."
The United States has third-party traffic agreements with a number of countries . A current list appears on page 51 of the November, 1966 issue of QST. Most of the countries in the list are in the Western Hemisphere or IARU Region 2, which has had its share of disasters and knows how valuable Amateur Radio can be in such instances . The other Regions, in general, see Amateur Radio as an experimental and operator-training service, and tend to call upon hams for help only during severe communications outages caused by natural disasters . To say the least, funding sources and their motivations will vary greatly by country . The regional effects will be different for each of the three geostationary satellites needed to provide worldwide coverage .
After Jan explained his Phase 4 concept and how much it would cost, he conducted a survey by show of hands of roughly 60 people who attentively sat through the briefing . Everyone in the audience, with perhaps a few nonrespondents, raised their hands in favor of going for a geostationary satellite systemhigher cost included . No one raised their hands in favor of either the status quo or throttling back the satellite effort .
It is one thing for Jan and his team to put together an engineering concept that makes sense . It is quite another thing to translate that unto money and action . There is a great deal of work to be done in the next year or so on the system definition . Then, once the parameters are agreed, the various engineering teams need to translate concepts into hardware and software in order to have everything fit together and work well before launch time . If you would like to be part of the Phase 4 engineering team, please write Jan immediately at the AMSAT address given below .
For those who missed the Dallas meeting, but would like the proceedings, they are available at $10 per copy from AMSAT, PO Box 27, Washington, DC 20044.-W4RI

# Correspondence

How to Convert A Frequency Counter to A Velocity Measuring Device Let's refer to the July 1986 Correspondence column-Mr Ennis already has a velocity meter in his frequency counter. A dimensional analysis shows this : K7FC's frequency counter measures Hertz . Some of us older amateurs remember when it was called cycles per second . But, what is a cycle? It is the rotational distance 2*pi radians, or in this case, the distance traveled as an electrical phase per unit of time elapsed . This is the definition of speed . Specify the direction of travel and the scalar changes into the vector quantity of velocity .
Mr Ennis can easily obtain a direct reading speedometer by arranging for the runners to open or close a switch each time they increment a foot/meter . Trip wires or light beams come to mind . If such a scheme is not realizable, there are consumer-grade, hand-held radars available which are commonly used in collegiate and professional athletics . K7FC could feed the return signal to his counter and measure the Doppler shift, but there would need to be signal conditioning and scaling .-Alan Horowitz, KZ1Y, SAIC, Systems Engineer, C3 Systems Div, 255 Hudson Rd, Stow, MA 01775
Calculate First
I read Jacob Schanker's, W2STM, article on inductance and capacitance magnification with interest (issue no . 56) . I've used this technique many times . Keep in mind, however, that currents or voltages are also magnified by this procedure. In transmitting applications, particularly when large values of magnification are used, you may exceed current or voltage ratings of components at even modest power levels . Looking at the capacitance magnification example given (L = 4.79 µH and C = 1000 pF), the reactance of the series combination is -j34 ohms. This is about equal to a 2600-pF capacitor at 1 .8 MHz. The actual reactance of the 1 000-pF capacitor is still -j88 ohms at 1 .8 MHz, however . The voltage appearing across the 1000-pF capacitor will be 2 .6 times greater than what would appear across a 2600-pF capacitor for a given amount of current . A similar analysis will show that inductance magnification can result in high currents through an inductor . So, before designing and building that new amplifier or antenna matching network based on magnification principles, it is a good idea to calculate the expected currents or voltages to make sure no components are overstressed!-Joe Fleagle, W0FY, 320 Green Trails Dr So, Chesterfield, MO 63017
New Hardware Runs Old Software A note of encouragement for those who have not had success with the hardware and software published in Thomas Strohl's, KA1VW, article, "Complete RTTY for the Timex," (issue no . 31, Sep 1984). After repeated attempts over a long period of time, my system began to work after a third Z80A® -SIO/0 was purchased and installed . My first two devices were defective and only produced gibberish on the screen . With the addition of the new interface, W1AW and RTTY bulletins are solid copy on my Timex TS-1000.-R. H. Knaack, Jr, W7FGQ, 11415-28th SW, Seattle, WA 98146
Audio Standards For Cellular
and ACSSB Systems
After several discussions with Jim Eagleson, WB6JNN, regarding ACSSB, I have a suggestion for setting audio standards . Cellular radios in the US must conform to a set of standards referred to as AMPS (Advanced Mobile Phone Service) . In the United Kingdom, they have standardized on the Total Access Communications System (TACS). These two systems are nearly identical .
The audio specifications define bandpass, pre and de-emphasis curves and companding performance . It is interesting to note that these standards are quite

# Bits

Vector Expands Its Line of Prototyping Cards
The Vector Electronic Co has expanded its line of IBM° prototyping cards with the addition of the 4617-3 . Designed for use with an IBM PC, AT, the 4617-3 has a pad-per-hole layout pattern with 0.042-inch holes on 0 .1-inch centers . This pattern simplifies the development of specialized circuitry and is particularly efficient for use with designs that require high component densities .
This board, with its plated-through similar to WB6JNN's optimum ACSSB system. Evidently, what is optimum for cellular radio's FM is also optimum for ACSSB. The AMPS audio processing could also be applied to amateur FM and even HF SSB for significant performance improvement with these systems as well . The advantages of audio processing standardization to the AMPS specs is twofold :
1) The standards are already in print and have been tested in an existing communications system .
2) Several integrated and hybrid component manufacturers are marketing inexpensive devices to satisfy the large demand for audio processing . For example, Signetics offers the NE570 series of compandors which are widely used by cellular radio manufacturers and ACSSB experimenters . Signetics is also designing a filter, pre and de-emphasis circuits and a dual-tone, multi-frequency circuit all on a CMOS IC . This will result in a two-chip solution for comprehensive FM or ACSSB audio transceive processing . In fact, this two-chip solution allows for full radio telephone duplex operation . Other manufacturers are also offering products conforming to the AMPS spec.
If such a standard is adopted, ACSSB experimenters and manufacturers could all have complementary audio process systems . Furthermore, the hardware solutions are inexpensive, simple, low power and available .-Robert J. Zavrel, Jr, W7SX, 707 Borello Way, Mountain View, CA 94041

holes, accepts any width DIP IC or Vector wire wrapping terminals . Power and ground buses are located on each side around the edges of the card and terminate to connectors . Connector pads on the board and accompanying bracket accept DB9, 15, 25 or 37-pin I/O connectors . The 4617-3 plugs into any open slot in the IBM AT . For further information, write the Vector Electronic Co, 12460 Gladstone Ave, PO Box 4336, Sylmar, CA 91342-0336; tel 818-365-9661 .-KA1DYZ December 1986 3

# HF Packet: Comments and Tips

By Gregory P . Latta, AA8V
438 Eastland Ave
Akron, OH 44305
A
nyone who has operated packet radio on the amateur HF bands is aware that problems exist with this mode of communication . The issue causing the most concern is the number of retries necessary to transmit correct data to a receiving station . It is in excess of what it should be .
Fortunately, this is not an inborn trait of HF packet operation . Rather, the problem is a result of packeteers operating their equipment incorrectly . Here are some suggestions that may help to improve the situation .
Poor Modems
One cause of excessive retries on the HF bands is that many people use the modem that came with their TNC. Most modems built into TNCs are designed for VHF and consist of little more than a simple bandpass filter and a phase-locked loop demodulator . Such a unit works fine for VHF operation, where there may be little noise or fading . However, the modems are unsuitable for HF packet operation at 300 baud . In fact, many perform poorly on RTTY at 45 .5 baud as well .
Manufacturers have been slow to realize the modem-TNC crisis. Several companies, however, have begun to respond by producing high-quality modems designed for HF operation . Note that there is nothing new in these modem designs . They are essentially the same proven designs that have been around for years in RTTY service . The modems are modified for the slightly different shift used in packet and a carrier-detect circuit is added . The modems are usually designed with a particular TNC in mind so they are easy to connect to. Because some modems are nothing more than a high-quality RTTY modem, the shift of most RTTY modems can be modified easily . In fact, the difference in the shift (30 Hz) is so slight that the unit may work satisfactorily in its unmodified state . In addition, carrier-detect circuits are simple and easy to add to most TUs .
The moral of this story is that if you plan to operate HF packet, get the proper modem! If you use the TNC's built-in modem, be sure it is designed for HF operation .
Timing Parameters
Improper setting of a timing parameter is another cause of excessive retries on HF packet . Many operators don't understand the importance of proper timing . Setting these timing parameters correctly can liter-4 QEX

ally make or break a packet radio link . Let me illustrate this with some examples . FRACK
FRACK is a parameter that controls the FRame ACKnowledgement time. It is a little known quirk of the TAPR-1 firmware (Heath, the first AEA TNCs and other TAPR-1 clones have it, too) . A TNC begins its timing procedure when transmission of a packet begins . During this period, the TNC waits for receipt of an ACK .
If the FRACK time elapses before an ACK is received, the TNC dumps the packet into the transmit buffer . Once the packet is placed there, it will be transmitted . Even receipt of the ACK one bit later than the FRACK time will not prevent the buffer from sending its data .
HF channels are busy because of varying propagation and lower baud rates (one fourth that of VHF packet) . Both factors tend to prolong the time it takes an ACK to get back to the sending station . Because it takes four times longer to send data, FRACK's timing must be increased significantly from the notch it was set to for VHF operation . If this is not done, a situation arises where the ACK time is less than the time it takes to send the packet . Since timing starts concurrently with the packet that is being sent, the TNC expects to receive the ACK before the packet is finished being sent! The result can be an infinite number of retries . This is a common problem with excessively long packets . If you are getting excessive retries for no apparent reason, try increasing FRACK .
TXD
TXD describes the time it takes for the transmitter to key up before data is sent . Here again, this parameter should be increased from its VHF setting ; HF rigs generally take longer to stabilize on transmit . Also, because FSK and not AFSK is used to transmit the signal, automatic gain control (AGC) is almost always used when receiving the signal . This helps to keep the signal level constant . Once a signal is received, some AGC circuits require a settling time . If this circuit does not stabilize, nonreceipt of one bit will result in an unnecessary retry .
If you are using AGC on your receiver, and it has several settings, set it to cw, FAST or to the minimum time constant possible . This setting helps the AGC circuit to stabilize faster . When transmitting a packet, assume the other operator's receiver is slow . Set the TXD a bit more than you may think is necessary . It helps in the long run . Other Parameters
PACLEN
PACLEN is a parameter that is set on the TNC and it means packet length . A PACLEN should not be greater than about 60! The HF bands are subject to noise, QRM and rapid fading . Even with a good modem, a fast AGC, and a good path, it is unreasonable to expect the path to hold up consistently for the time it takes to send a long packet at 300 baud . If you think that sending a long packet and "hoping it will make it" is the answer to successful HF operation, forget it . At 300 baud, the band has only to drop out or fade for 3 ms and a bit will be lost . That means another retry! MAXFRAME
MAXFRAME is the number of unacknowledged packets that can be enroute at any given time . If too many packets are outstanding, the TNC will not transmit any more data. MAXFRAME is typically 4 on VHF . On HF, it should be 1 or 2 . If the path is particularly good, it can be increased to 3 or 4 . The trouble with an excessive MAXFRAME setting (especially with excessive PACLEN) is that one station can overtake the frequency for long periods of time . With MAX-FRAME kept to 1 or 2, and PACLEN limited to say 60, the length of each packet is kept to a minimum . (Transmitter "on time" is important on HF . With different propagation, more stations may be heard than if you were listening to a local VHF network .)
Final Comments
There is more to getting on HF packet than simply recalibrating the on-board modem, setting Hbaud to 300 and connecting everything to the rig . HF packet can be a successful ., reliable mode, but only if it is approached intelligently . Among other things, thoroughly read the instruction manual that came with your TNC. Most manuals have a section dedicated to on-theair operation . To enjoy the HF packet mode and help eliminate QRM, obtain a good understanding of how the TNC parameters affect operation .
The above recommendations are for normal QSO type contacts . Some of the parameter settings should be modified during file transfers, when using bulletin boards and other specialized operations . However, from on-the-air experience, these suggestions and settings should be correct for the average amateur . See you on the air!

# Experimenting With Direct-Sequence Spread Spectrum

By Andre Kesteloot, N4ICK
6800 Fleetwood Rd
McLean, VA 22101

Introduction
During the past several years, AMRAD (Amateur Radio Research and Development Corp) has been conducting experimentation with spread spectrum technology . 1 . 2 As a member of the group, I decided to build a board that would demonstrate some practical aspects of direct-sequence spread spectrum (DSSS). I chose a carrier frequency of 2 MHz so that the phenomena could easily be displayed on any low-frequency (5-MHz bandwidth) oscilloscope likely to be available to the average radio amateur . The equipment, which can transmit and receive data, test square waves and Morse code signals, was demonstrated at the September 1986 AMRAD meeting in Vienna, VA . Description
Referring to Fig 1, it is fairly easy to conceive of an amateur spread-spectrum communication link if an existing external reference, such as a local TV or radio transmitter, is used . 3 In this experiment, the external reference is a 4-MHz oscillator . A 2-MHz carrier is obtained by dividing the reference frequency by 2 ; this carrier is also used as clock for a pseudo-random generator. Data is xoRed with the output of the pseudo-random generator and the result is xoRed with the carrier . This produces a binary phase shift keyed direct sequence spread spectrum (BPSK DSSS) signal . At the receiving site, a pseudo-noise sequence similar to that created at the transmitter, is generated and synchronized to the original one . By mixing this sequence with the reference carrier, it is possible to extract the original data . In my demonstration model, points T and R were connected to each other with a jumper . In a practical application, point T would be connected to an antenna via an amplifier ; point R would similarly be connected to a receiving antenna, AGC amplifier and the like .
Circuit Operation

1

Reviewing the transmitter stage in

Notes appear on page 9 .

R F
GENE

P N
GENE RATOR

DATA
CONDITIONER

TRANSMITTER

EXTERNAL
REFERENCE

Fig 2, U1 is a 4-MHz DIP oscillator that is used as the reference frequency . U2A, a 4013 D flip-flop divides this frequency by 2 to produce a 2-MHz carrier (referred to as CA) . The 2-MHz frequency is further divided by 1,000 (through three consecutive 4017 divide-by-10 stages, U4, U5 and U6) to produce a 2-kHz square wave . This signal is used as a test square wave (Figs 3, 4 and 5) and also serves as clock for another 4013 D flip-flop, U2B . Under normal conditions, the Morse key is open, the D input of U2B is low and its 0 output is low . When the key is pressed, the D input goes high . At the next clock pulse Q goes to + 5 V . When the key is released, the D input goes low again, and at the next clock pulse, Q also goes low . Thus, the data (in this case the Morse sequence) is now synchronized to the 2-kHz clock, itself a submultiple of the 2-MHz carrier . This synchronized operation ensures phase-coherent switching .

RECEIVER

Fig 1-A block diagram of a possible radio amateur's spread-spectrum communications link . The external reference signal can be received from a TV or radio transmitter .

The 0 output of U2B is our data, or DA. The 2-MHz carrier (CA) is also used to clock U7, a 74164 7-stage linearfeedback shift register connected as a pseudo-random noise generator (PN), with feedback taps at outputs 1 and 7 . Feedback is applied using an XOR stage U8B, while U8A is connected as an inverter . (This is one of the FCCauthorized PN sequences . For a more complete study of this circuit, see note 3 .) The PN sequence is available at pin 2 of U7 and is called the original code or oco. It is modulo-2 added to the data output of U2B in an xoR stage, U8C, the output of which is oco x DA . This signal is XORed with the 2-MHz carrier (CA in U8D) to produce the output signal oco x DA x CA, a BPSK DSSS signal . (In reality, this signal would be applied to an antenna using a power amplifier . On my experimental board, it is simply jumpered to the input of the receiver .)

December 1986 5

U1
4-MHz
XTAL
OSC
MODULE

14

8

B

LOCK

14

USA
7486

6 QEX

' 16
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
+ 5V
0
U4
4017

DECADE
CLOCK DIVIDER

CLOCK
ENABLE

RESET GND

6

+5V
0

14
VCC

PN GENERATOR

0+5V

U88

CARRY
OUT

1k

8

12

OG OA

U2A
4013

12

14

9
CLEAR

3

+5V

14
CLK
VCC
FLIP-FLOP
D VSS

U7
74164

m

+5V
0

13

16
VCC

7

DECADE
CLOCK
DIVIDER

U5
4017

CLOCK
ENABLE RESE

GND
| 15

CARRY
OUT

8

12

+5V
0

m

U3A
4049

+5V

IOOPF

T
U3C

TRANSMITTER

+5V
0

16
CC

DECADE
CLOCK
DIVIDER

13
15
KEY | 4 .7k

U2B

7N6 9
D

2

U6
4017

MHz REFERENCE CARRIER

CARRY
OUT
CLOCK
ENABLE RESE

GND
8

CLK

1

2

FLIP-FLOP

U16 B

2

U3B

SI
DATA
SELECT

CODE

DATA

Q
O
x
2-kHz

g
U
CLOCK | 0

9

UBC

12

13

EXCEPT AS INDICATED, DECIMAL VALUES OF CAPACITANCE ARE
IN MICROFAFIADS (pF ); OTHERS ARE IN PICOFARADS ( pF ),
RESISTANCES ARE IN OHMS,
k= SIC M - ' II)U ooo-

M=MYLAR

TANTALUM

U8D

CA

Fig 2-A complete schematic digram of the DSSS transmitter and receiver stages . Operation of the circuit is explained in the text .
Q1-2N4402, PNP transistor . | U2-CD4013BC dual D flip-flop. | U4, U5, U6-CD4017BC decade counter/
S1-SPDT switch. | U3, U11-CD4049UBC hex inverting | divider with 10 decoded outputs.
S2-Normally open push-button switch . | buffer. | U7, U13, U20-74164 8-bit serial-in
U1-4-MHz DIP crystal oscillator . | | parallel-out shift register .

RECEIVER

LC o

U17D

B

LCO

CLOCK | 8
8 | 2 OCO

UI7B

U17C

LOCK

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
CA ∎ LCO
LOAD
ADJ
I k

R2 0.1
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
USIA
7486
3

A

VCC | CLEAR

CIA 0B OC OD OE
OF OG
4

4

5

5
0C 0 0

6

6

9

10

10

LOAD
ADJ
Ik

11
0E OF 0

U13
74164

SHIFT

REGISTER | GND

12

2

PN GENERATOR | CLEA

A

CC

6 )D

4

U148

12

13
14

UI4C
10

U14D
11

5V U15A
4070
3
/ | U15B
| 4

10

560 | IOk | 3.3
| GAIN

U10
MC1496P

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
0.05
100

GAIN ADJ
CARRIER
INPUT

OUTPUT
BALANCED
MODULATOR

SIGNAL
INPUT
j

V EE

OUTPU

12

/

3.3 k

3

15

3

9

R-S LATCH

5 | 0
12

I/0 4

U12D

U18C

SELECT
LINE

0

U20 74164

+5V

1

2
T

100
8 | U11
/ / | 3 .3

4049

DC LEVEL
SHIFTER | / | +S V

AUDIO OSCILLATOR

+5V
0

DATA

U8, U9, U17-7486 quad 2-input exclusive U14, U15-CO407OBC quad 2-input U22-CD4001BC quad 2-input NOR OR gate .
exclusive OR gate . | buffered B series gate .
U10-MC1496 balanced demodulator. | U18-C040668C quad bilateral switch.
U12, U16-CD4011 quad 2-input NAND B
U19-74LS04 hex Inverter .
series gate . | U21-CD4072BC dual 4-Input OR gate .

+5V
-OV

December 1986 7

Fig 3-A DSSS carrier is shown at the jumper between the transmitter (output of 1.1813) and receiver. The scanning rate is 1 µs/div .

Fig 4-The upper oscilloscope trace shows a 2-kHz test square wave before transmission at the output of U2B. The lower trace is the same signal after decoding at the receiver, at the output of U11A . There is no discernible difference between the two signals . The scanning rate is 0 .2 ms/div .

8 QEX

Reviewing the receiver stage, we can see that the input signal (oco x DA x CA) and CA (the carrier derived from the external reference) are both applied to the inputs of an XOR stage, U17D . At the beginning of a transmission, no data is transmitted and the result of xoRing (oco x CA) and CA is thus oco, the original code sequence . This sequence is serial-loaded into U13, a 7-stage shift register clocked by CA.
Another 74164 shift-register stage, U20, is connected as a PN generator using the same pseudo-noise sequence as the one used in the transmitter . (In Amateur Radio spread spectrum, it is mandatory to announce in clear the kind of register used . This enables both operators of the radio link to set their PN generators to the same sequence .) When the receiver is turned on, U20 is clocked at twice the normal 2-MHz rate . This 2 x clock is generated by applying the 2-MHz CA to U15D, a multiply-by-two stage, the output of which is shaped by a Schmitt trigger (U19A, U19B) . U18A and U18B (part of a 4066-quad switch) are connected as a SPDT switch . U18B is normally

nwe .---

Fig 5-The output of PN generator U7, at pin 2 . The scanning rate is 5µs/div .

closed, U18A is normally open and the 4-MHz clock signal is applied to the PN generator U20 .
Since U8 and U20 use the same feedback taps, they produce the same random sequences . Our goal is to synchronize both signals so that they will be in phase . As was discussed earlier, when no data is transmitted, the output of U13 is oco, the original code sequence . The words produced by U13 and by U20 are compared, bit for bit, in a magnitude comparator comprised of XOR stages U14A, B, C, D, U15A, B, and C, quad input OR gates U21A and B and NAND gate U16A . As U20 is clocked at twice the rate of U13, its output tries to "catch up" with that of U13. There will be one instant when both output words are equal bit for bit . At that time, all outputs of the seven XOR stages will be low and the output of U16A goes high, driving the output of U17A low . This ill uminates the "lock" LED and drives the Q output of U12C low. In turn, U18B opens and U 1 8A closes, thereby switching the clock rate of U20 from 4 MHz to 2 MHz. From then on, both U7 and U20 will produce the same PN sequences, will be clocked at the same frequency and will be in phase (oco = LCO) . The edgetriggered RS latch (U12C, D) prevents further changes at the output of the magnitude comparator from influencing the clock speed, something that would otherwise happen whenever data is received .
Loss of sync between oco and LCO can be simulated by momentarily grounding pin 9 of U7 . oco and LCO will now be out of phase. When this occurs, press the reset button-in the absence of data, or when data is low, the magnitude comparator output is compared to the clock speed selector (by bypassing the RS latch through U18C) to resynchronize LCO to oco.
If Morse code is sent, for instance, notice that the lock LED extinguishes while the data is being transmitted . This occurs because the code now extracted from the DSSS transmission is no longer in phase with either oco or LCO . The latter two, however, are still in phase, and as soon as the key is released, the LED lights again .
The carrier (CA) and the Lco are now XORed in U9A, the output of which is CA x LCO. This signal is applied to one of U1O's inputs, a MC1496P/1596 balanced demodulator . 4 The other input is fed with the received DSSS signal (oco x DA x CA) . Since oco = LCO, the output of the demodulator is the data DA . (To adjust the three potentiometers associated with U 10, an oscilloscope should be connected to U10, pin 6 . Both input potentiometers should be adjusted for no overloading, and the 1-kSl potentiometer between pins 2 and 3 can usually be left in the minimum resistance position to provide maximum gain for this stage .) As U10 operates from + 12 V, a dc voltage shifter composed of Q1 and U11A is used to shift the data to TTL levels . In my experimental board, this data is then used to gate ON and OFF an audio oscillator (U12A and B) that is connected to a small outboard audio amplifier and speaker .
Conclusions
Using components and test equipment readily available to the average radio amateur, it is possible to experiment with DSSS and gain hands-on experience and a better understanding of the fundamentals of this newly authorized technology . No attempt was made to optimize this demonstration board . The use of some circuitry was dictated by the availability of a particular IC, or because a portion of a quad gate was yet unused . No doubt several gates could have been saved, other more elegant ways of achieving the same results could have been developed and additional circuit simplifications could have been carried out . However, this was never meant to be a finished product, but simply a test bed for ideas. The reader is invited to dream up their own refinements .
If some quad-gate ICs were shared between the transmitter and receiver sections on the prototype board, they were renumbered (for clarity) and shown as separate ICs in Fig 2 . (Incidentally, the 555 timer, located at the bottom left of the board [cover photo], is an adjustable clock generator only used in some early experiments . It is not shown on the schematic.) The three square potentiometers near the center of the board are associated with demodulator U10 . The reset switch is mounted on the rear of the board and is not shown in the photograph .
To build a radio link for 440 MHz, XOR stages U8C, U8D, U9A and U17D would have to be replaced with doubly-balanced mixers such as the SBL-1 from Micro-Circuits, or the M53T manufactured by Magnum Microwave .5 ,6 You'll need a reference carrier higher than 440 MHz, and for that purpose a local UHF-TV transmitter carrier comes to mind . At both amateur sites, a free-running oscillator could be used at approximately the reference frequency and a phase-lock loop (PLL) to lock this oscillator to the external reference TV transmitter would be necessary . This arrangement is equivalent to the CA on my demonstration board . In the experiment described earlier, no preamble signal was sent for syn-

# Bits

Communication Equipment Protection With a host of communication equipment using solid-state devices, voltageline surges and interruptions can cause havoc with computer files and other data transmission systems . Many manufacturers have taken a serious look at this problem and each have marketed their own protective devices . The following protective products are only a few of the many that are available .

Modem and Portable Computer Protection Electronic Specialists, Inc has expanded their computer protection line to include the Modem/Power/Static Pac . This device is a complete protection package for the traveling portable computer . It has combined broadband ac power filtering, extended range spike suppression, modem RF filtering, modem spike suppression and a static discharge plate . Power is available from a conventional 3-prong outlet and a CEE-22 universal portable computer power connector. A 6-foot power cord is provided and modem connection is through standard modular RJ-1 1 conchronization purposes . Sync was acquired before data was transmitted . On 440 MHz, it may be advisable to send a short preamble to synchronize the divider chain from which the 440-MHz carrier will be derived .
Finally, to transmit audio sine waves rather than square waves, it should be relatively easy, after raising the low clock rate from 2 kHz to 20 kHz, to apply that new clock and the audio sine waves to a conventional 555 pulse-width modulator, for example . To raise the clock rate, lower the divider ratio from 1/1,000 to 1/100 by eliminating one of the 4017 divide-by-ten stages .
Further Reading
Radio amateurs who reference readily available literature on spread spectrum will find ample mathematical treatment, plenty of block diagrams and a remarkable paucity of detailed schematic diagrams or specific information on hardware . Chapter 21 of The ARRL 1986 Handbook for the Radio Amateur7 offers a good theoretical background on the subject . The articles by Scholtz6 and Pickholtz et a19 should also be referenced. Details of prototype realization are available in a paper by Van Der Gracht 10 and to a lesser extent in an article by Maskara and Das . 11 Finally, anyone contemplating involvement in spread spectrum should have access to the fundamental book by Dixon . 12

nectors . Model MPS-2(22) sells for $184 .95. Kleen Line Modem protection is available for 4- and 8-pin telephone modular connectors . The system (Model PDS-11/SUP) uses modern semiconductor, metal oxide varistor and gas discharge tube suppression techniques to suppress damaging telephone and power line spikes . Model PDS-11/SUP sells for $109 .05 . A 40-page color catalog describing communication equipment protection is available from Electronic Specialists, Inc, 171 S Main St, Natick, MA 01760 ; tel 617-655-1532 . The catalog describes numerous standard, off-the-shelf products, custom designs and hot-line problem solving . Ask for catalog 861 ; it is available free of charge.
New Conditioned Uninterruptible Power System is a Line-Saver°
Kalglo Electronics Co has added a new standby uninterruptible power system to its existing line of power conditioning equipment . Designated the Line-Saver, Model LS500, the unit is applicable to home or small business computer market situations . It is engineered to give trouble

Acknowledgements
I am grateful to AMRAD members Hal Feinstein, WB3KDU, and Mike O'Dell, N4NLN, for their suggestions and encouragements .

Notes
1 H. Feinstein, "Spread Spectrum, Frequency Hopping, Direct Sequence and You," QST, Jun 1986, p 42 .
2 A . Kesteloot, "Practical Spread Spectrum : A Simple Clock Synchronization Scheme," QEX, Oct 1986, p 4 .
3 See note 2 .
4 R. Hejhall, "MC1596 Balanced Modulator, Application Note AN-531," Motorola Semiconductor Products, Inc, Phoenix, AZ 1982 .
5 Micro-Circuits Co, Inc, RR 1, PO Box 518, New Buffalo, MI 49117, tel 616-469-2727 .
6 Magnum Microwave Corp, 365 Ravendale Dr, Mtn View, CA 94043, tel 415-968-9281 .
7 M . Wilson, ed ., The ARRL 1986 Handbook for the Radio Amateur, Newington : ARRL, 1985 . 8 R . Scholtz, "The Spread Spectrum Concept," IEEE Transactions on Communications, Vol Com-25, No . 8, Aug 1977.
9 R . Pickholtz, D . Schilling and L . Milstein, "Theory of Spread-Spectrum Communications-A Tutorial," IEEE Transactions on Communications, Vol Com-30, pp 855-884, May 1982 .
10 P . Van Der Gracht and R . Donaldson, "Communication Using Pseudo-Noise Modulation on Electric Power Distribution Circuits," IEEE Transactions on Communications, Vol Com-33, No . 9, Sep 1985 .
11 5. L . Maskara and J . Das, "Concatenated Sequences for Spread Spectrum Systems," IEEE Transactions on Aerospace and Electronic Systems, Vol AES-1 7, No. 3, May 1981 . 12R. Dixon, Spread Spectrum Systems, New York; Wiley, 1976 .

free standby back-up power available in 117/234 V, 60/50 Hz, with 500 W capacity .
The unit uses pulse width modulation (PWM) technology to regulate the RMS ac output voltage for greater efficiency to various load conditions . The PWM ac output increases battery efficiency which in turn increases battery back-up time . The unit is also furnished with an internal 24 V sealed rechargeable battery, two Spike-Spiker° voltage surge protected and EMI/RFI filtered ac outlets, audible and visual power failure warning system, test mode indicator and switch, replaceable external fuses, compact in size with external 24 V dc battery connectors to allow for mobility and extended hold-up time .
The Line-Saver weighs 27 lbs and has a footpoint of 0 .64 square feet . The unit comes with a 6-foot detachable 3-prong heavy-duty grounded cord with a CEE-22 connector. Suggested retail price is $795.00 . For further information contact Kalglo Electronics, Co, Inc, 6584 Ruch Rd, E Allen Twp, Bethlehem, PA 18017 ; tel 215-837-0700 .-KA1' DYZ
December 1986 9

# A Two-Tone Generator With Very Low Distortion

By George Pelissier, Fi BBI
4 Square Poussin
F-78150 Le Chesnay, France Translated by George W . Allen, N1BEPt
A
two-tone audio signal is commonly used to test the linearity of an SSB transmitter. The amplitude of each signal should be identical, and the signals and their mixing circuitry should be set to produce the least distortion possible . With this in mind, two signals that are not harmonically related should be chosen . This article describes a two-tone generator that produces a 900- and 2100-Hz signal combined so that all har-

10 QEX

R

R4
+15 V

-15V
R3

DI

UI
LM 741

C2

R5 Y D2
10k

16k

TEST

monics are greater than 60 dB below the level of the desired signal . (The measurements were performed in the laboratory using a spectrum analyzer .)
Circuit Description
The two-tone generator shown in Fig 1 is essentially composed of two classical Wein-bridge oscillators Al and A2 (see Fig 2), which oscillate at 900 and 1200 Hz, respectively. The nonlinear net-

Fig 1-The schematic diagram of the two-tone audio generator.

1

R15
+15 V
D3

-15V
R14

U2
LM 741

C6

RIG 7
D4
Ok

RIO
150

m

work of the two diodes assures that enough gain is present to maintain oscillation at a low distortion level . The 10-kS2 resistor in parallel with the diodes serves to reduce crossover distortion . The oscillator circuiit has a high output impedance . Any change in the load changes the active point of the diodes, which in turn changes the output amplitude . This phenomenon can be used to control the generator . More on this later .

EXCEPT AS INDICATED, DECIMAL VALUES OF CAPACITANCE ARE
IN MICROFARADS (µF ) ; OTHERS ARE IN PICOFARADS ( pF );
RESISTANCES ARE IN OHMS ;
k = 1000, M = 1000 000.

50 kfl

Fig 2-The Wein-bridge oscillator . Two of these oscillators are used in the generator to produce the 900- and 1200-Hz signal .

O dB
-3dB

1P

LOG 0
V;

+ 6 dB/
OCTAVE

a

WO
-LOG w
Z~\w

1

1
J

RI+R2
L~(il
C RI

~~ C RI 2R2

(B)

-6 dB/ OCTAVE

Fig 3-A shows a typical band-pass filter. R2 adjusts the center frequency . B is the filter's peaked response curve . Frequency shifts are made with the bandwidth and frequency held constant .

decreases . Moreover, the action of the paired diodes further reduces the distortion . In my circuit, I have chosen fixed resistor values for Po that were determined experimentally.
Reducing Distortion
The simplest and most efficient way to reduce the distortion of the sinusoidal signal is with an active filter . Amplifiers A3 and A4 are set respectively to the frequency of each oscillator to satisfy this condition . Each filter is a band-pass filter with a peaked response curve of that shown in Fig 3. The filter's selectivity is such that an output which is nearly perfectly sinusoidal (Figs 4 and 5) can be obtained . The detailed theory of these filters are discussed elsewhere .i-

# wunmmnmmmm

## 1111III1111∎∎Bull

## 11111AR111130! MINIM

Fig 4-A 900-Hz signal Is produced by the active filter . The horizontal scale is 0.5 ms/div and the vertical scale is 1 V/div .
Construction and Choice
of Components
My generator was constructed on a PC board; no special precautions were taken . All components must tie 1% tolerance, particularly the capacitors in each filter . The capacitors used should either be polycarbonate, mica, Mylar or polystyrene . Their quality is important for good stability and having a two-tone generator that performs well .
Finally, which ± 15 volt power supply is used for the generator is a decision left to you . Many bipolar power supplies that are able to adapt itself to the generator exists . (Don't go below ± 15 volts .) This generator will assist those operators who like to fuss over the adjustment of their linear amplifiers . And, Amateur Radio operators who have access to an oscilloscope or a spectrum analyzer can easily test the two-tone audio generator's performance .

## NNNNNNNINUM lill)IIi11i11111111 Ij~ wIll IIUIIIIIIII II II IIIIIIIIII

11111'111111111111.111111

## I11'∎'1'11 1~1'll~ll'll'1 iiiiffibm mum

Fig 5-A 2100-Hz signal produced by the
active filter . The horizontal scale is
0 .5 ms/div, while the vertical scale reads 1 V/div.

With the heart of our generator realized, the two sinusoids must be adjusted in the summing amplifier A5 . The inverse input to A5 appears to be at virtual ground; this means that the output of each filter sees a resistance of 10 kO with respect to ground . By connecting these components to virtual ground, we are ensured that these filters and their associated oscillators do not interact .

The unloaded frequency of oscillation will be stable if R1 = R2 and C1 = C2 at
FF | 1 | (Eq 1)
| . = 2aR1C1
The potentiometer (P 0) is adjusted to where oscillation begins . At that setting, the inverted input to the op amp is at a potential approximately equal to eo/3 . -
When oscillation begins, the diodes start

Adjustment
to conduct and their impedance reduces | Three adjustments must be performed .
the ratio of negative feedback . Adjusting | P1 and P2 set each filter to the frequency
Po varies the output amplitude . Note that of the associated oscillator . They also set in this arrangement, the more the ampli- the output amplitude of each filter . As we tude increases, the more the distortion

have seen, changes in the oscillator's load also change the amplitude and the frequency of the signal, but this is not critical . Instead, set P1 and P2 to obtain identical outputs from each filter at pin 6 . In my case, I set the levels to four volts P-P . These adjustments are very sensitive and the use of an oscilloscope will be helpful . Those who do not have access to a scope can use an electronic voltmeter to set the amplitudes . Do not exceed four volts P-P or output distortion may result . If everything is correctly adjusted, the output signal should look like that shown in Fig 6 . P3 sets the output level .

NIEL
ti

NIA MW

il1ri1J

NUNN

ii',A

I.,"

# altow

## MOEN

# boas

Fig 6-The oscilloscope trace shows a 900- and 2100-Hz signal, both with equal amplitudes .

Notes
IM. Wilson, ed, The 1986 ARRL Handbook, (Newington : ARRL, 1985), p 25-28 . 2Burr Brown, Operational Amplifiers, Design and

Applications
3National Semiconductor, "Easily Tuned Sine Wave Oscillators," App Note LB-16. 4Sescosem : Application Manual for Linear

Integrated Circuits, vol 1 .
tG. Pelissier, "A Two-Tone Generator With Very Low Distortion," Radio-Ref, Dec 1985, p 772 . December 1986

1 1

# Xerox 820-1 Compendium Part 5

By Dave Borden, K8MMO
AMRAD, PO Drawer 6148
McLean, VA 22106-6148

Talking to Fred
In our previous encounter with frequency hopping, the Xerox 820-1 board was hooked to an ICOM IC-2AT hand-held transceiver to frequency hop rather slowly (10-100 hops/second) . 32 This month we will lay the groundwork for high-speed frequency hopping on HF . Note that the new FCC rules do not allow this, but our AMRAD Special Temporary Authorization (STA) does . 33 Before we can hop cleanly, it is necessary to have a Fred . What is a Fred?
The Fred Williams Synthesizer
In 1984, QST published an article on a remarkable synthesizer that produced a clean signal from 1 Hz to 7 MHz, in 1-Hz steps . 34 The synthesizer used a TRW D/A converter and hard-to-get parts . It was designed and built by Fred Williams, an employee of the TRW LSI Products Div . AMRAD members were able to obtain the parts, an EPROM and the schematic to build one . In a subsequent article, QST published information on a hand-set frequency controller to allow the synthesizer to be programmed easily . 35 At the same time, a revised schematic was available ; it used less expensive parts that were more obtainable . Also, A & A Engineering (2521 W LaPalma Ave, Unit K, Anaheim, CA 92801 ; tel 714-952-2114) produced kits for both the synthesizer and controller . AMRAD ordered one kit each and Elton (Sandy) Sanders, WB5MMB, constructed the units . AMRAD named the project and synthesizer "Fred" in honor of its designer.
Xerox 820 Talks to Fred
Sandy brought the completed units to my laboratory to demonstrate that they worked. Once convinced that both units were working properly, Sandy constructed a cable to run between the Xerox 820 parallel port and Fred . The details of that cable appear in Fig 7 . Note that Fred expects serial programming . The three lines that run to Fred from the computer are responsible for changing the unit to the desired frequency . •
Frequency Load (Transfer Line, "Change Freq Now")
*Transfer Clock (Clock transitions for digit valid)

32 Notes appear on page 15 .

12 QEX

XEROX
620-1

FROM XEROX 620-1

•
Frequency Control Data (Desired Freq-24 bits)
Hal Feinstein, WB3KDU, and I programmed Fred to do several tasks . We first hooked Fred's output to a Yaesu FT-7 HF transceiver . The FT-7 wants a VFO frequency of 5 .0-5 .5 MHz, just perfect for Fred . The FT-7's socket that accepts the external VFO resides on the back of the rig . The socket looks like a 5-pin DIN, but it is not . The coaxial cable from Fred was soldered to the FT-7 and the power to the internal VFO was cut . Using the handset controller that Sandy built from the kit, we had frequency control of the FT-7 and could move up and down the band . We quickly unplugged the controller and plugged in the Xerox
820. The program in Table 1 controls Fred; let's start in a simple manner. Enter the 24 binary digits (1 or 0) . When the 24th digit is typed in, Fred will change to the new frequency and the FT-7 will hear whatever is on frequency .
PACANSWR
The basic complaint about packet bulletin board systems (PBBS) is that users interact with other local PBBS computers on 145 .01 MHz. This causes

5 TO 5 .5 MHz

DATA

TRANSFER CLOCK

FREQUENCY LOAD

TO FRED
Fig 7-A Xerox-to-Fred-to-Yaesu interface allows the operator to have computer control of the FT-7 transceiver . Refer to the lower drawing : On the frequency line, send the frequency as 24-binary bits, with the most significant bit (MSB) first . Toggle the clock line for each binary digit sent . Lower the transfer line at the beginning of the transfer; raise the line toward the end .

problems because the computers are channel hogs . Computers and human typists do not share the same frequency well ; the computer always wins . Therefore, I offer some suggestions : (1) Marry the AMRAD frequency agile ICOM-2AT transceiver with the packet radio TNC code from Phil Karn, KA9Q, and produce the Frequency Agile Bulletin Board ;
(2) The PACANSWR machine .
For years, people have used telephone answering machines. Many people dislike them, but they help to screen calls . Thanks to Ward Christensen's MODEM program, many people now leave their TNCs in the capture mode (capture all traffic on disk during a 24-hour period) . If your TNC is set for the monitor mode, you will receive all traffic on disk, too . If you disable the monitor mode, then traffic sent to you exclusively is received only . The problem? Callers who know you have a capture mode will leave a message, others won't .
What is needed is a packet answering machine. This device informs the caller that they have reached my station, but that I am busy and they can leave a message .
Let's take the easy way out . Disable the

Table 1
Frequency Set Program in BASIC

monitor mode on the packet board so it will only respond to connect requests . I did this and captured one hour's worth of monitor mode and examined it . I was receiving the WB2MNF PBBS being relayed through WB2RVXO, WB4APR6 and WB4JFI5 as well as normal nightly traffic on the busy 145.01-MHz channel . The result was 16 kbytes of disk . By disabling the monitor mode, the TNC is discriminative and will ignore beacons, PBBSs and so on . It also makes the code simpler .
Let's look for *CNCT* and *DISC* in our code . On connection, the packet caller is informed that our PACANSWR program is ready to capture traffic .
The hardware is simple and does not require a schematic . Run a four-conductor wire from your computer serial port DB25 female connector to the Vancouver/Ashby DB25 female connector. This wire need only contain a hookup for pin 2 (Frame ground), pin 2 and 3 (receiver and send) and pin 7 on the Vancouver side . The Macintosh° computer uses RS-422, which has a DB9 connector instead of a DB25 . Wire the chassis ground to DB9, pin 1 . Signal ground goes to pin 3, transmitted data goes to TXD, pin 5 and receiver data goes to RXD, pin 9 . Do not bother with handshaking . The Macintosh does not handle it correctly unless a serial driver is installed .
I coded Table 2 in Microsoft° BASIC 2 .0 for the Macintosh . It is easier to understand than the C language . Notice the BASIC used is not like one you've seen before . There are no line numbers and this style of BASIC resembles FORTRAN . There are nice syntax structures included like the IF-THEN-ELSE statements . If are familiar with BASIC, this code should be easy to follow .
That's the program . I keep it simple . The Macintosh has an 8530 serial port that is handled in BASIC by setting up a

Table 2
PACANSWR in Microsoft° Basic 2.0
REM
REM --- PACKET ANSWER MACHINE PROGRAM REM
PACANSWR :
GOSUB INIT
OPEN "0",#4, "CAPTURETEXT"
REM
REM N IS THE NUMBER OF ASTERISK RECEIVED AS IN
REM *CNCT* OR *DISC*
REM M IS A FLAG, 1 = CONNECTION AND 0=NO CONNECTION REM
N=0
M=0
LOOP :
P$ = INPUT$(LOC(1),1)
PRINT P$ ;
PRINT #4, P$ ;

PRINT #1, K$
GOTO LOOP
QUIT :
CLOSE #4
END
REM
REM INITIALIZATION SUBROUTINE
REM MONACO MOSPACED NON-PROPORTIONAL, FONT REM 9 POINT ALLOWS 80 CHARACTERS PER. LINE REM XOR TEXT WITH WHAT IS ON THE SCREEN REM
INIT .
TEXTFONT 4
TEXTSIZE 9
TEXTMODE 1
REM SETUP COMMUNICATIONS 8530 PORT OPEN "COM1 :300,N,8,1" AS 1 LEN=2000 RETURN
REM
REM CNCTDISC SUBROUTINE
REM DETERMINE WHICH IS GOING ON REM
CNCTDISC :
N=0
IF M = 0 THEN GOSUB CNCTMSG :RETURN IF M = 1 THEN GOSUB DISCMSG
RETURN
REM
REM IF CONNECTION ESTABLISHED, INFORM CALLER REM
CNCTMSG :
M = 1
PRINT#1,"YOU HAVE CONNECTED WITH K8MMO, DAVE" PRINT#1,"BUT HE IS UNAVAILABLE, SO PLEASE" PRINT#1,"LEAVE YOUR MESSAGE AT THE BEEP AND" PRINT#I,"HE WILL, GET BACK TO YOU . . . THANKS" PRINT#1,"DAVID'S COMPUTER . . .SKINNY MAC" PRINT#1,"

BEEP"
RETURN
REM
REM DISCONNECTION, RESET FLAG AND ANNOUNCE TO CRT REM
DISCMSG :
M=0
PRINT "DISCONNECTION"
RETURN

Continued on page 15.

December 1986

1 3

10 REM HANDSET BY XEROX 820 KEYBOARD FRED OUTPUT 20 REM ARRAY OF 24 BINARY DIGITS FOR FREQUENCY 22 DIM D(24)
25 PRINT "BEGINNING FREQUENCY SET OF FRED"
26 REM BEGIN BY INITIALIZING PARALLEL PORT
27 REM SET PORT A TO BIT MODE
28 OUT 9,207
29 REM SET PORT A TO ALL OUTPUT BITS
30 OUT 9,0
31 REM DISABLE INTERRUPTS ON PORT A
32 OUT 9,64
33 REM CLEAR ALL LINES FOR ACTION, RAISE TRANSFER 34 OUT 8,4
35 REM THE BIT FREQ SET LOOP, QUIT WITH CTRL-C 36 FOR I = 1 TO 24
37 PRINT "THE CURRENT BINARY DIGIT IS-",I
40 INPUT D(I)
50 IF D(I) = 1 THEN GOSUB 1000
60 IF D(I) = 0 THEN GOSUB 2000
70 NEXT I
75 REM THE FREQ IS NOW SET, SO DO IT
80 OUT 8,4
85 REM DO IT AGAIN UNTIL CTRL-C SAYS QUIT
90 GOTO 35
1000 REM SEND A ONE
1005 REM SET A ONE, TOGGLE CLOCK, SET XFER LOW 1010 OUT 8,1
1020 OUT 8,3
1030 OUT 8,0
1035 RETURN
2000 REM SEND A ZERO
2005 REM SEND A ZERO, TOGGLE CLOCK, SET XFER LOW 2010 OUT 8,0
2020 OUT 8,2
2025 OUT 8,0
2030 RETURN

IF P$ = "*" THEN N = N + 1 IF N = 2 THEN GOSUB CNCTDISC IF LOC(1) > 0 THEN LOOP
K$ = INKEY$
IF K$ = "@" THEN GOTO QUIT IF K$ = "" THEN LOOP

>50

# Focus on technology above 50 MHz

# Measuring Antennas

Hams have always loved experimenting with antennas, and VHFers are no exception . Since most VHF and UHF antennas are relatively small, they are especially attractive to the workshop builder and tinkerer . There are many excellent "cookbook" designs in the amateur literature that, if duplicated exactly, will perform as predicted . Unfortunately many of us don't always follow the recipe and try to improve the design or modify it to use the materials at hand. In either case, it's a good idea to be able to test the antenna . It's no fun lugging a new array to the top of your hundred foot tower, only to find a high back-to-front ratio or twelve lobes, all equal in amplitude, coming off the front! This month's column is by no means a complete treatise on antenna gain measurement ; it will, however, help a few readers get started in a very interesting field .
The Measurements
Assuming the antenna we want to measure is matched to 50 ohms, the important measurements are 1) absolute forward gain with respect to a dipole or other reference radiator, and 2) pattern (response in all directions, related to the main lobe). Qualitatively speaking, at least for directional antennas such as dishes and Yagis, we would like the antenna to have as much gain as possible off the front and as little as possible everywhere else . If these measurements can be made, even roughly, on the ground, there won't be any surprises when the antenna gets up on the tower. Gearing Up
Any antenna-measuring setup has four basic components : 1) a range ; 2) a signal source; 3) a detector ; and 4) a standard-gain reference antenna . See Fig 1 . RF at the measurement frequency is fed into the source antenna, which is aimed at the antenna under test . Then, a reference level is established . This is accomplished by using a reference antenna with known gain . Any subsequent measurements of unknown antennas are compared to this known reference level . Simple eh? Theoretically, yes . In practice, no . There are many ways to get false readings . . . read on .
The Range
It would be nice if we could all set up

1 4 QEX

SOURCE
ANTENNA

RANGE

Fig 1-Simple antenna-gain measuring setup .

a dish) and is always longer than is convenient or possible . Shorter fields are usable, but they tend to compress the higher gain readings .

an accurate range to do antenna measurements! An ideal antenna range would be in outer space, I guess, but about the best we can do is a large flat area with no trees or buildings nearby . There should be nothing around that will reflect signals into the test antenna from the wrong direction . The worst things to have near an antenna range are large metal structures such as cars, buildings, towers and so on . These will really throw off readings in an unpredictable manner, especially when measuring sidelobes and antenna patterns .
Of course, we do have a reflector that we must live with-the earth . If the source antenna is placed close to the ground, say within a few wavelengths, the source signal will appear to originate from a point below the source antenna . This is because the reflected signal from the ground combines in phase with the direct signal . This is okay and actually has the effect of increasing the gain of the source antenna by a couple of decibels . If the source antenna is many wavelengths above the ground, the reflected signal is probably very low compared to the direct one. In this case, the signal appears to originate directly from the source antenna .
The other important feature of an antenna range is that it must be long enough to put the source in the far field of the test antenna . The far field (or Fraunhofer region) starts at a distance where the wave originating from the test antenna appears to be planar-a requirement for accurate antenna measurement . The far field starts at a distance of 2D 2/X . D is the major dimension of the test antenna (length of a Yagi or diameter of

### Source and Detector

The RF source and detector must be compatible to provide a linear response over the measurement range . There are a number of source/detector combinations that will provide reasonable accuracy for amateur measurements . With the vast amount of good test equipment on the surplus market, you should have no problem coming up with the right gear. The equipment described here is available at flea markets at affordable prices .
A simple setup uses a clean CW transmitter and a high-gain antenna with a clean pattern at the source end . The detector can be a microwattmeter such as the HP431 or HP435. These wattmeters use a bolometer sensor and will measure power directly in decibels in a very linear fashion . Since bolometer detectors are not as sensitive as diode detectors, you will need a good amount of ERP at the source . A couple of watts of RF and a relatively high-gain source antenna should do the trick .
Other detectors are more sensitive, but these require a 1000-Hz modulated source . The HP415 SWR detector is such an instrument . lit uses a diode detector mount and is calibrated directly in decibels (at least some of the models are) .
No matter which setup you use, be sure to check the linearity of the system . The easiest way is to insert an attenuator of known value in the line from the

By Bill Olson, W3HQT
Box 1655A, RFD 1
Burnham, ME 04922

ANTENNA UNDER
TEST OR STANDARD
REFERENCE ANTENNA

MICROWATTMETER
DETECTOR test antenna to the detector and see how much the detector meter reading changes. For example, if you insert a 6-dB pad, the meter reading should decrease by 6 dB .
Another simple detector is a receiver tuned to the test frequency . You can read the AGC voltage with a VTVM to get rough measurements, but there are too many places for nonlinearities here . I don't recommend this system for real accuracy.
A more sophisticated system, used at many antenna-gain measuring contests, is shown in Fig 2 . It consists of an HP416B ratiometer as a detector and a 1 -kHz modulated source . The '416, as the name implies, compares the signal coming into two separate ports and reads the difference in decibels . In this system, a reference-port antenna is left connected to one port at all times . All measurements are compared to the signal level from the reference antenna . This system has the desirable feature of taking out inaccuracies caused by variations (over time) in the output power from the source . The ratiometer uses a square law (diode) detector, so be sure to check for linearity when using this system .
Standard Reference Antenna
The final critical part of the antenna measuring system is a standard-gain reference antenna with which all unknown antennas are to be compared . This is usually an antenna with moderate and very predictable gain . The EIA standard-gain antenna, a pair of dipoles over a groundplane is one such antenna. Various horn antennas with predictable performance can also be built .
If you don't have access to one of these standard antennas, an antenna of known performance (for example, the RIW-13 432-MHz antenna you measured at last year's VHF conference and which has been hanging up in the garage since) is probably as good as anything . Although your absolute numbers may be off a decibel or two, you really are only looking for system improvement . Relative readings are fine . Do not try to use a dipole as a standard reference . It will respond to signals from all over, including reflections from the test equipment . The higher the gain of the standard reference antenna, the better.
Making Measurements
Once you've gathered and assembled your test range, making the measurements is fun . Turn on the source and point the source antenna toward the detector end of the range . Walk back to the detector end and probe the field with the standard-gain antenna . Look for the maximum reading on the detector . You may have to move a bit or climb a ladder to get the peak .

C1-kHz

MODULATOR

SIGNAL
SOURCE
- -ED

SOURCE
ANTENNA

Next, record the reading on your detector meter . The meter reading should be in decibels, probably referenced to a milliwatt (dBm) . This is your reference level . Attach the test antenna to the same feed line in place of the standard-antenna and peak for maximum signal . If you know the gain of the standard, the gain of the antenna you're testing can be calculated . If, for example, your standard antenna reads 3 .5 dB on the meter and your test antenna reads 6 .5, your test antenna has 3-dB more gain than the standard . So, if the standard has 7 dB gain, your test antenna has about 10-dB gain .
If your measurement system has

2000-character buffer. When a character comes to the computer from the Vancouver board, an interrupt occurs and the character is placed in the 2000-character buffer at the next available place . Using the LOC statement, INPUT$(LOC(1),1), one character is input to us from the 2000-character buffer . If LOC(1) is 1, this means at least one character is in the buffer . When the buffer is cleared, LOC(1) is a zero and we can check the keyboard .
This program is based on the terminal program supplied with the BASIC on the Macintosh . If you own a Macintosh, give it a try . If each packeteer had a program like this, most of the bulletin boards could be eliminated .
Disk Drives for the Xerox 820-1 Canon MDD2 double-sided, doubledensity drives were purchased from B .G . Micro (PO Box 280298, Dallas, TX 75228; tel 214-271-5546) . The drives are 2/3 height, which means that two occupy more space than one Shugart SA450 . They make fine drives for the Xerox computer . After two of these drives came into
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

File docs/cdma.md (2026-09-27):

# From DSSS link to multiuser CDMA

Direct-sequence CDMA assigns different spreading signatures to simultaneous users in the same channel. A receiver projects the composite waveform onto a user's code; code cross-correlation, relative power and chip timing then determine how much multiple-access interference remains. This extension studies those three effects with an energy-normalized BPSK baseband model.

## Signal and receiver architecture

For user `u`, each bit maps to `b_u ∈ {+1, −1}` and a unit-energy signature `c_u`. The received chip vector in one symbol interval is

```text
r = Σ_u sqrt(P_u) b_u c_u + j + n
```

Here `P_u` is energy relative to the desired user, `j` is an optional single tone, and each real AWGN chip has variance `N0/2`. The code matrix `C` contains one signature per user. The model offers 32-chip Walsh rows and 31-chip circular shifts of the laboratory PN recurrence. A chip-phase control rotates interfering signatures within each symbol interval. It exposes loss of Walsh orthogonality while retaining a common symbol boundary.
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

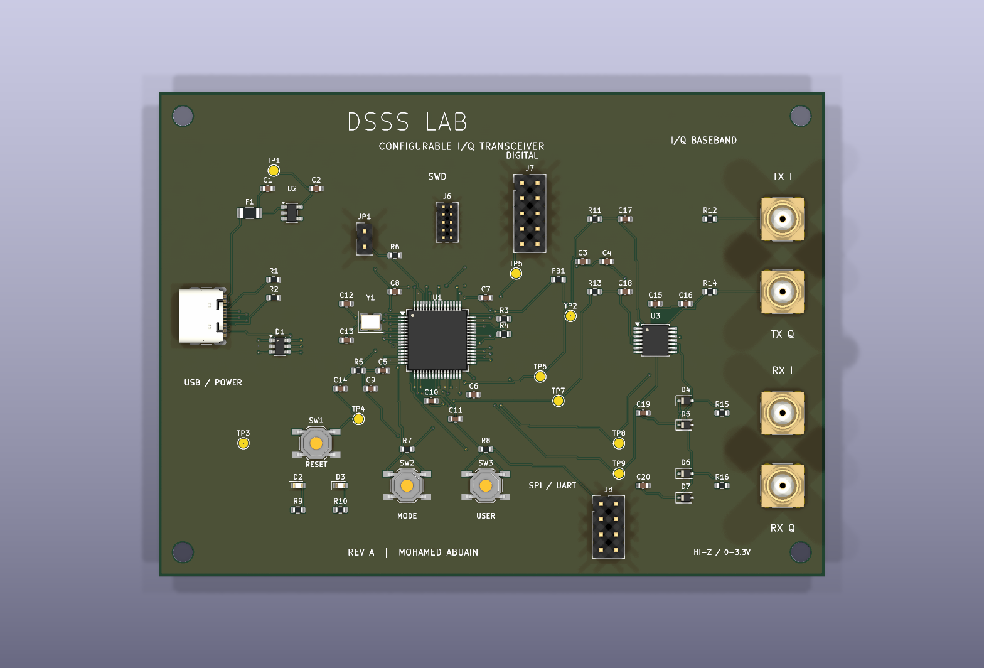
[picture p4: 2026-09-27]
hardware/configurable/renders/board-top.png

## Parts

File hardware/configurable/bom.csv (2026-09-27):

Reference | Value / part | Footprint | Description
J1 | USB-C / CONTROL | Connector_USB:USB_C_Receptacle_GCT_USB4105-xx-A_16P_TopMnt_Horizontal
F1 | 500mA PTC | Fuse:Fuse_1206_3216Metric
U2 | AP2112K-3.3 | Package_TO_SOT_SMD:SOT-23-5
C1 | 4.7uF | Capacitor_SMD:C_0603_1608Metric
C2 | 4.7uF | Capacitor_SMD:C_0603_1608Metric
FB1 | 600R@100MHz | Resistor_SMD:R_0603_1608Metric
C3 | 4.7uF | Capacitor_SMD:C_0603_1608Metric
C4 | 100nF | Capacitor_SMD:C_0603_1608Metric
R1 | 5.1k | Resistor_SMD:R_0603_1608Metric
R2 | 5.1k | Resistor_SMD:R_0603_1608Metric
R3 | 22R | Resistor_SMD:R_0603_1608Metric
R4 | 22R | Resistor_SMD:R_0603_1608Metric
D1 | USBLC6-2SC6 | Package_TO_SOT_SMD:SOT-23-6
U1 | STM32G474RET6 | Package_QFP:LQFP-64_10x10mm_P0.5mm
C5 | 100nF | Capacitor_SMD:C_0603_1608Metric
C6 | 100nF | Capacitor_SMD:C_0603_1608Metric
C7 | 100nF | Capacitor_SMD:C_0603_1608Metric
C8 | 100nF | Capacitor_SMD:C_0603_1608Metric
C9 | 1uF | Capacitor_SMD:C_0603_1608Metric
C10 | 100nF | Capacitor_SMD:C_0603_1608Metric
C11 | 1uF | Capacitor_SMD:C_0603_1608Metric
Y1 | 8MHz / CL 10pF | Crystal:Crystal_SMD_3225-4Pin_3.2x2.5mm
C12 | 15pF | Capacitor_SMD:C_0603_1608Metric
C13 | 15pF | Capacitor_SMD:C_0603_1608Metric
R5 | 10k | Resistor_SMD:R_0603_1608Metric
C14 | 100nF | Capacitor_SMD:C_0603_1608Metric
R6 | 10k | Resistor_SMD:R_0603_1608Metric
JP1 | BOOT | Connector_PinHeader_2.54mm:PinHeader_1x02_P2.54mm_Vertical
SW1 | RESET | Button_Switch_SMD:SW_SPST_TL3342
SW2 | MODE | Button_Switch_SMD:SW_SPST_TL3342
SW3 | USER | Button_Switch_SMD:SW_SPST_TL3342
R7 | 10k | Resistor_SMD:R_0603_1608Metric
R8 | 10k | Resistor_SMD:R_0603_1608Metric
R9 | 1k | Resistor_SMD:R_0603_1608Metric
D2 | GREEN | LED_SMD:LED_0603_1608Metric
R10 | 1k | Resistor_SMD:R_0603_1608Metric
D3 | AMBER | LED_SMD:LED_0603_1608Metric
U3 | TLV9064IPWR | Package_SO:TSSOP-14_4.4x5mm_P0.65mm
C15 | 100nF | Capacitor_SMD:C_0603_1608Metric
C16 | 1uF | Capacitor_SMD:C_0603_1608Metric
R11 | 1k | Resistor_SMD:R_0603_1608Metric
C17 | 1nF | Capacitor_SMD:C_0603_1608Metric
R12 | 100R | Resistor_SMD:R_0603_1608Metric
R13 | 1k | Resistor_SMD:R_0603_1608Metric
C18 | 1nF | Capacitor_SMD:C_0603_1608Metric
R14 | 100R | Resistor_SMD:R_0603_1608Metric
R15 | 1k | Resistor_SMD:R_0603_1608Metric
C19 | 1nF | Capacitor_SMD:C_0603_1608Metric
D4 | BAT54WS | Diode_SMD:D_SOD-323
D5 | BAT54WS | Diode_SMD:D_SOD-323
R16 | 1k | Resistor_SMD:R_0603_1608Metric
C20 | 1nF | Capacitor_SMD:C_0603_1608Metric
D6 | BAT54WS | Diode_SMD:D_SOD-323
D7 | BAT54WS | Diode_SMD:D_SOD-323
J2 | TX I | Connector_Coaxial:SMA_Amphenol_132291_Vertical
J3 | TX Q | Connector_Coaxial:SMA_Amphenol_132291_Vertical
J4 | RX I | Connector_Coaxial:SMA_Amphenol_132291_Vertical
J5 | RX Q | Connector_Coaxial:SMA_Amphenol_132291_Vertical
J6 | SWD | Connector_PinHeader_1.27mm:PinHeader_2x05_P1.27mm_Vertical
J7 | DIGITAL | Connector_PinHeader_2.54mm:PinHeader_2x05_P2.54mm_Vertical
J8 | SPI / EXPANSION | Connector_PinHeader_2.54mm:PinHeader_2x04_P2.54mm_Vertical
TP1 | +3V3 | TestPoint:TestPoint_Pad_D1.5mm
TP2 | +3V3_A | TestPoint:TestPoint_Pad_D1.5mm
TP3 | GND | TestPoint:TestPoint_Pad_D1.5mm
TP4 | NRST | TestPoint:TestPoint_Pad_D1.5mm
TP5 | CHIP_CLK | TestPoint:TestPoint_Pad_D1.5mm
TP6 | DAC_I | TestPoint:TestPoint_Pad_D1.5mm
TP7 | DAC_Q | TestPoint:TestPoint_Pad_D1.5mm
TP8 | ADC_I | TestPoint:TestPoint_Pad_D1.5mm
TP9 | ADC_Q | TestPoint:TestPoint_Pad_D1.5mm

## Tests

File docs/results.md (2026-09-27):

# Simulation results

The experiments on this page use the Python communications model. The main seed is 20260920. Full environment metadata is stored in `../results/run_metadata.json`; the pulse-shaping example uses seed 99.

## Noise baseline

The run uses 60,000 bits at each Eb/N0 point. Both receivers use equal information-bit energy, bit rate and sample rate. Confidence intervals and error counts are retained in [awgn.csv](../results/awgn.csv).

| Eb/N0 (dB) | Theoretical BPSK BER | BPSK simulated BER | DSSS simulated BER |
|---|---|---|---|
| 0 | 0.0786496 | 0.0797667 | 0.0775667 |
| 2 | 0.0375061 | 0.0361333 | 0.0371333 |
| 4 | 0.0125008 | 0.0122333 | 0.0118833 |
| 6 | 0.00238829 | 0.00208333 | 0.0025 |
| 8 | 0.000190908 | 0.000183333 | 0.000133333 |

BER comparison

## Interference

At Eb/N0 = 8 dB, each interference point uses 30,000 bits. The following examples all use J/S = +10 dB; frequency placement changes the outcome.

| Interferer | BPSK BER | DSSS BER |
|---|---|---|
| tone_inband | 0.395333 | 0.000366667 |
| tone_outofband | 0.000333333 | 0.00473333 |
| chirp | 0.198733 | 0.0009 |
| burst | 0.00623333 | 0.0056 |

The in-band tone demonstrates rejection by despreading. The out-of-band tone demonstrates the benefit of the narrower unspread receiver. The comparison depends on interferer frequency and receiver bandwidth. See [interference.csv](../results/interference.csv) and the exact frequencies in [methodology](methodology.md).

Interference comparison

## Acquisition

Known 16-bit preamble, 127 chips/bit, 65 integer delay candidates, and three on-grid CFO candidates. The table reports joint delay/CFO estimation across 100 trials per noise level.

| Eb/N0 (dB) | Correct joint delay/CFO estimates | Trials | Success rate |
|---|---|---|---|
| -5 | 47 | 100 | 47.0% |
| 0 | 97 | 100 | 97.0% |
| 5 | 100 | 100 | 100.0% |

The [burst example](../examples/burst_link.py) recovers a CRC-protected text message after a simulated 29-sample delay, +0.0002 cycles/sample CFO and 0.83-radian phase offset. Acquisition estimates phase from the noisy preamble. There is no off-grid tracker or false-alarm-controlled detector.

## Pulse shaping

RRC shaping uses four samples/chip, a 10-chip filter span and a 2 Mchip/s chip rate. Occupied bandwidth below contains 99% of the estimated PSD power. Noise tests use 4,000 bits per point; those counts are too small for precise low-BER comparisons between roll-off values.

| RRC roll-off | 99% occupied bandwidth (MHz) | Observed errors / bits |
|---|---|---|
| 0.2 | 2.156 | 2 / 4000 |
| 0.35 | 2.316 | 1 / 4000 |
| 0.7 | 2.836 | 0 / 4000 |

Pulse shaping

## Other outputs

The [CDMA extension](cdma.md) adds a four-user near–far sweep, three receiver choices and a [source CSV](../results/cdma_near_far.csv) with 45 comparisons. Its [figure](../results/figures/cdma_near_far.png) shows how a one-chip phase shift changes Walsh-code separation and how multiuser detectors handle strong interferers.

| CSV | Experiment |
|---|---|
| `payloads.csv` | Random, pattern, text and PCM bit recovery |
| `packets.csv` | CRC frame failures versus Eb/N0 |
| `impairments.csv` | Uncompensated phase/CFO/timing, phase noise, ADC and IQ sensitivity |
| `multipath.csv` | Single-finger versus exact-known-channel matched combining |
| `rayleigh.csv` | Symbol-independent fading with perfect CSI |
| `near_far.csv` | Synchronous two-user interference with a second Gold-family sequence |
| `repetition.csv` | Three-copy soft decoding with energy normalized per information bit |
| `pn_sequence.csv`, `pn_acf.csv` | Exact recurrence and correlation |
| `spectrum.csv` | Rectangular-pulse PSD-derived bandwidth |
| `hardware_trace_excerpt.csv` | Short ideal digital trace; not a measured scope export |

All paths above are under `results/`. Zero observed errors are reported with a finite confidence upper bound where BER metrics are used. Multipath combining uses known taps; fading experiments assume perfect receiver CSI.

## Validation status

The Python unit suite has 22 passing tests. It covers PN period/table, autocorrelation, energy, noiseless recovery, theoretical BER, CRC, acquisition, channel alignment, interference power, repetition normalization, impairment identities, confidence intervals, invalid inputs, PSD power, RRC recovery, burst decoding and CDMA code/receiver behavior. Python and GNU Octave also run in the [validation workflow](../.github/workflows/validate.yml).

GNU Octave and native MathWorks MATLAB have both validated the MATLAB-compatible implementation, including the shared deterministic vectors. The first native run used MATLAB build `2026.1.999`, completed all assertions and experiment runners, and uploaded the generated results as a GitHub Actions artifact.

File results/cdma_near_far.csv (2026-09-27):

users | family | chip_offset | near_far_db | ebn0_db | symbols | method | jammer_db | errors | ber | max_crosscorr
4 | walsh | 0 | 0 | 8 | 12000 | matched |  | 0 | 0.0 | 1.1102230246251565e-16
4 | walsh | 0 | 0 | 8 | 12000 | decorrelator |  | 0 | 0.0 | 1.1102230246251565e-16
4 | walsh | 0 | 0 | 8 | 12000 | mmse |  | 0 | 0.0 | 1.1102230246251565e-16
4 | walsh | 0 | 6 | 8 | 12000 | matched |  | 0 | 0.0 | 1.1102230246251565e-16
4 | walsh | 0 | 6 | 8 | 12000 | decorrelator |  | 0 | 0.0 | 1.1102230246251565e-16
4 | walsh | 0 | 6 | 8 | 12000 | mmse |  | 0 | 0.0 | 1.1102230246251565e-16
4 | walsh | 0 | 12 | 8 | 12000 | matched |  | 0 | 0.0 | 1.1102230246251565e-16
4 | walsh | 0 | 12 | 8 | 12000 | decorrelator |  | 0 | 0.0 | 1.1102230246251565e-16
4 | walsh | 0 | 12 | 8 | 12000 | mmse |  | 0 | 0.0 | 1.1102230246251565e-16
4 | walsh | 0 | 18 | 8 | 12000 | matched |  | 0 | 0.0 | 1.1102230246251565e-16
4 | walsh | 0 | 18 | 8 | 12000 | decorrelator |  | 0 | 0.0 | 1.1102230246251565e-16
4 | walsh | 0 | 18 | 8 | 12000 | mmse |  | 0 | 0.0 | 1.1102230246251565e-16
4 | walsh | 0 | 24 | 8 | 12000 | matched |  | 0 | 0.0 | 1.1102230246251565e-16
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

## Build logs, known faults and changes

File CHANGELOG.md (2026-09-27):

# Changelog

## CDMA receiver study — 28 September 2026

- Added a four-user direct-sequence CDMA model with Walsh and PN-shift signatures, chip-phase offsets and controlled near–far power.
- Added matched-filter, decorrelating and linear MMSE detection with deterministic receiver tests.
- Published the 45-condition BER sweep, comparison figure and browser-based signal explorer.
- Recast the implementation and historical-report notes around architecture and measurement conventions.

## Rev A hardware design — 27 September 2026

- Added a connected STM32G474 schematic and four-layer PCB for configurable I/Q experiments.
- Added USB-C, dual transmit/receive channels, analogue filtering and protection, SWD, expansion headers and test points.
- Added the BOM, pin map, PCB renders and configurable payload/PN/modulation interface specification.
- Updated the project overview to lead with the Rev A architecture.

## Documentation update — 27 September 2026

- Reworked the README and supporting pages around the circuit, laboratory captures and simulation results.
- Added the December 1986 QEX issue and linked its source article.
- Removed internal CV preparation and source-archive inventory pages.

## 0.1.1 — publication and CI maintenance

- Published the complete project repository with source code, evidence, datasets and generated figures.
- Passed the Python and GNU Octave jobs in GitHub Actions and retained both result artifacts.
- Passed the native MathWorks MATLAB workflow and retained its generated result artifact.
- Updated GitHub-maintained actions to Node.js 24-compatible major versions.
- Scoped automatic native MATLAB runs to relevant implementation, vector and workflow changes.

## 0.1.0 — initial software extension

- Added Python DSSS primitives and MATLAB counterparts with shared deterministic vectors.
- Added AWGN, interference, payload, CRC, acquisition, multipath, fading, near-far, front-end impairment and pulse-shaping studies.
- Added a framed burst receiver that acquires integer delay and grid CFO and corrects phase before decoding.
- Verified the report's inverted-feedback PN recurrence and documented rate/gain corrections.
- Preserved selected individual hardware evidence and source files with QEX attribution.
- Organized the historical KiCad layout alongside the later configurable board design.
- Prepared automated Python/Octave checks and a manual native MATLAB workflow.

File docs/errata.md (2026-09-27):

# Engineering notes on the original report

The [original laboratory report](original-report.pdf) records the circuit, test setup and observed waveforms. The following conventions make its measurements easier to interpret alongside the newer models.

## Clock, data and spreading

The circuit uses seven active stages of an eight-stage 74164 register. Its XNOR feedback has a 127-chip period; the all-zero start state is valid and the all-one state is fixed. At a 2 Mchip/s clock, a 1,000-chip data-clock interval lasts 500 µs. The direct 2 kHz square-wave input has 500 chips in each high or low interval. These are two distinct test configurations, so code period, data interval and square-wave fundamental are kept separate in the model.

The ratios of 1,000 and 500 chips per interval correspond to 30.0 and 27.0 dB, respectively, when expressed as `10 log10(chips/interval)`. They describe nominal spreading ratios. The [simulation study](results.md) evaluates error rates under stated interference conditions; it does not use those ratios as measured receiver gain.

## Signal path and synchronization

The recorded bench connection carries the transmitter output to the receiver through a wired path with a shared reference. The logic trace reproduces PN generation, spreading and carrier XOR operations. The communications receiver adds preamble correlation and a finite delay/CFO search; its acquisition results are recorded separately from the bench observations.

The synchronization indicator reflects the clock-switch logic state. Timing quality in the newer model is evaluated from correlation peaks and decoded-frame checks. A PN sequence also provides code separation, while payload confidentiality requires a separate cryptographic layer.

## Design lineage

The underlying 1986 circuit is credited in [design references](attribution.md). The [Rev A board](../hardware/configurable/README.md) develops a different, programmable baseband architecture, with its own routed PCB, bill of materials and design checks. The original source files remain available with the report as the laboratory record.

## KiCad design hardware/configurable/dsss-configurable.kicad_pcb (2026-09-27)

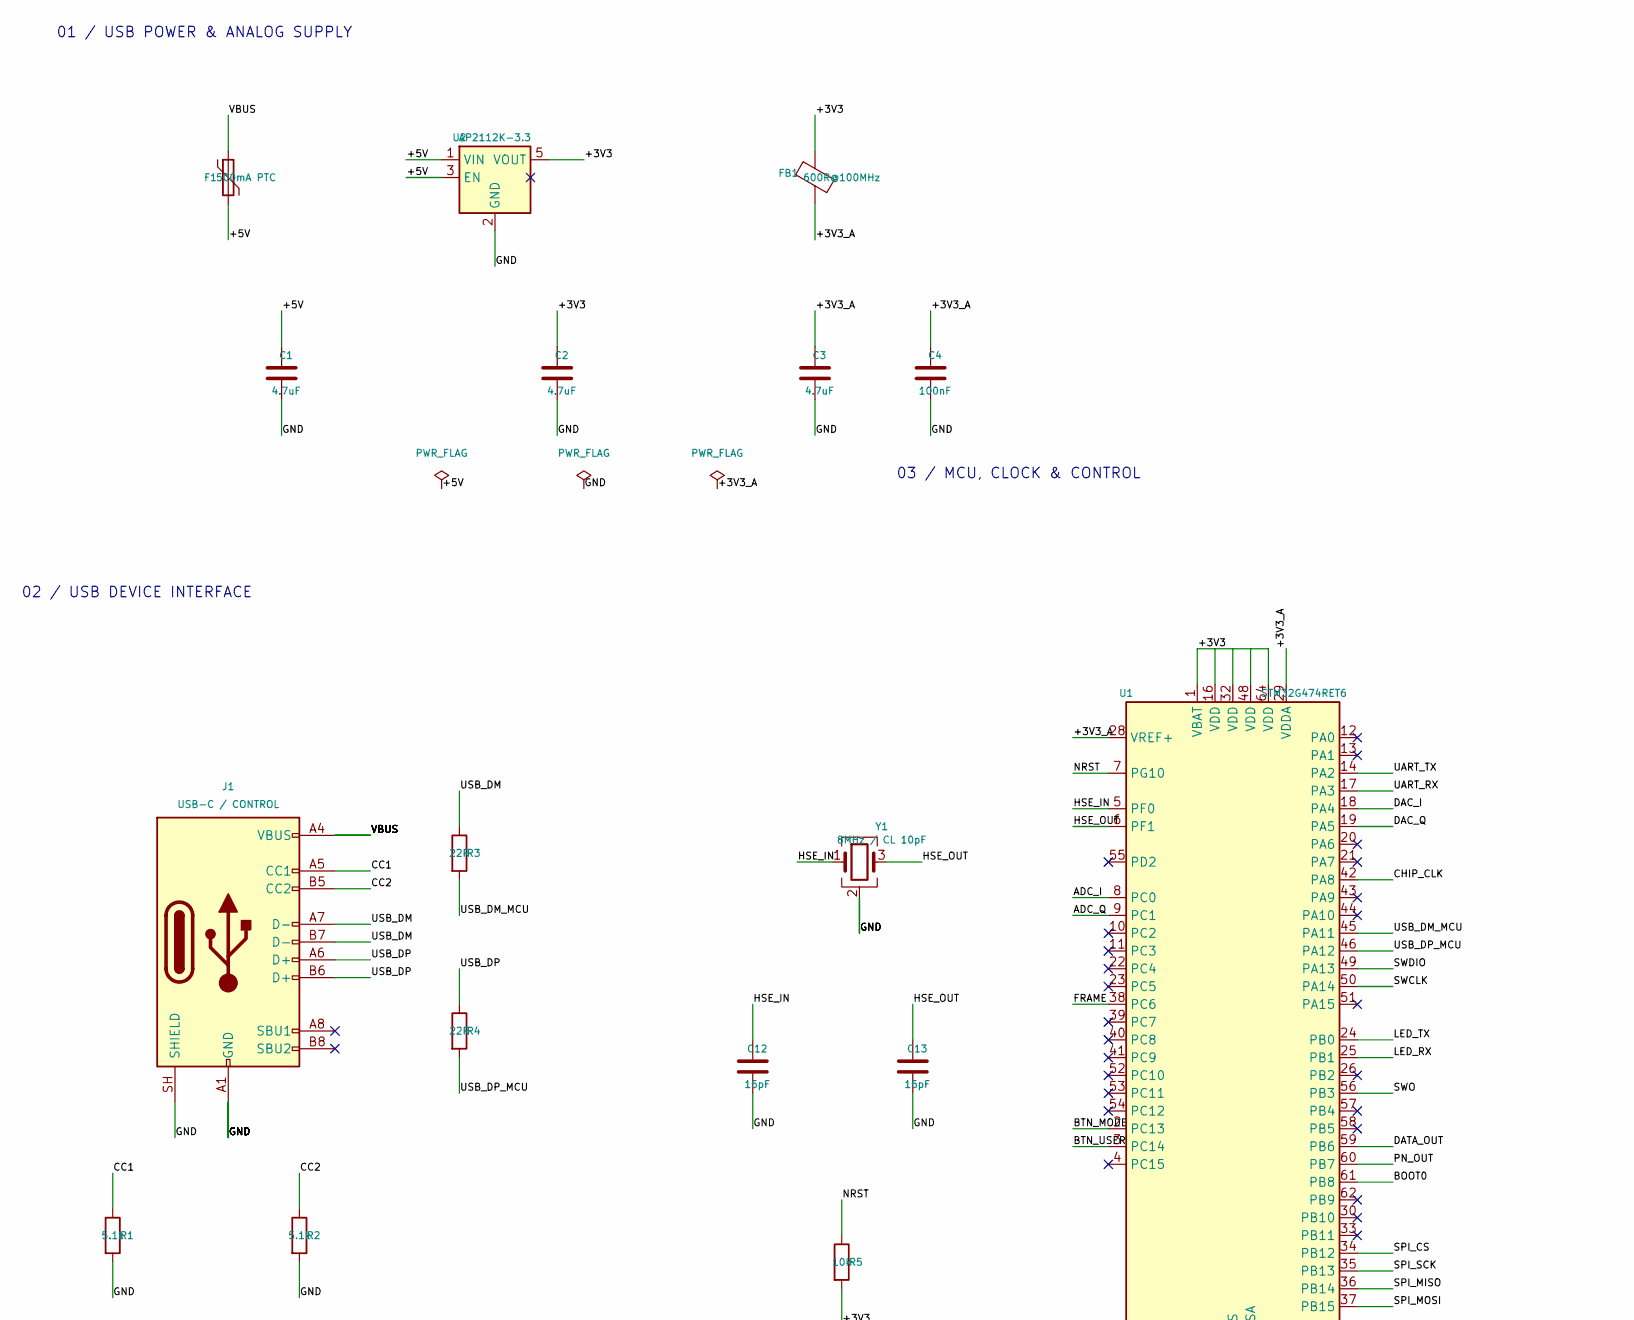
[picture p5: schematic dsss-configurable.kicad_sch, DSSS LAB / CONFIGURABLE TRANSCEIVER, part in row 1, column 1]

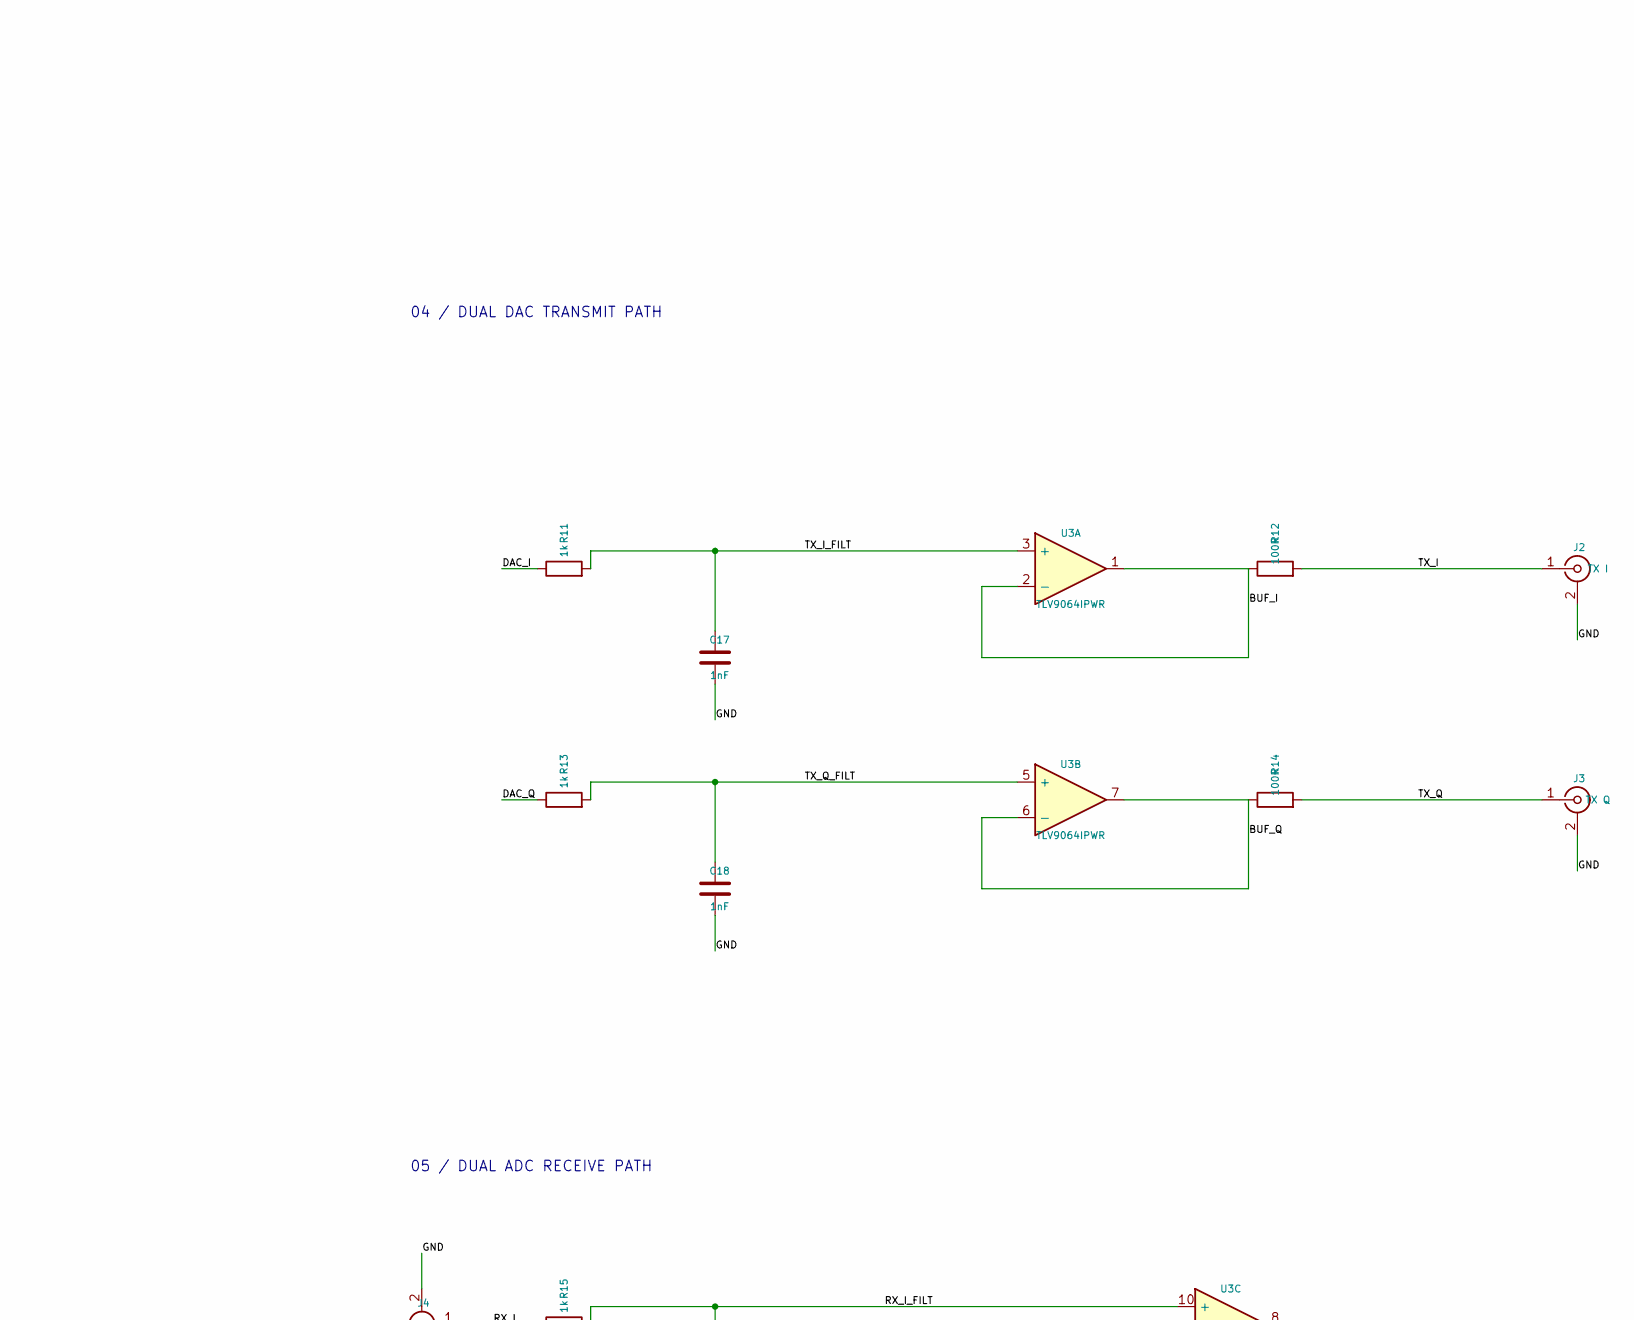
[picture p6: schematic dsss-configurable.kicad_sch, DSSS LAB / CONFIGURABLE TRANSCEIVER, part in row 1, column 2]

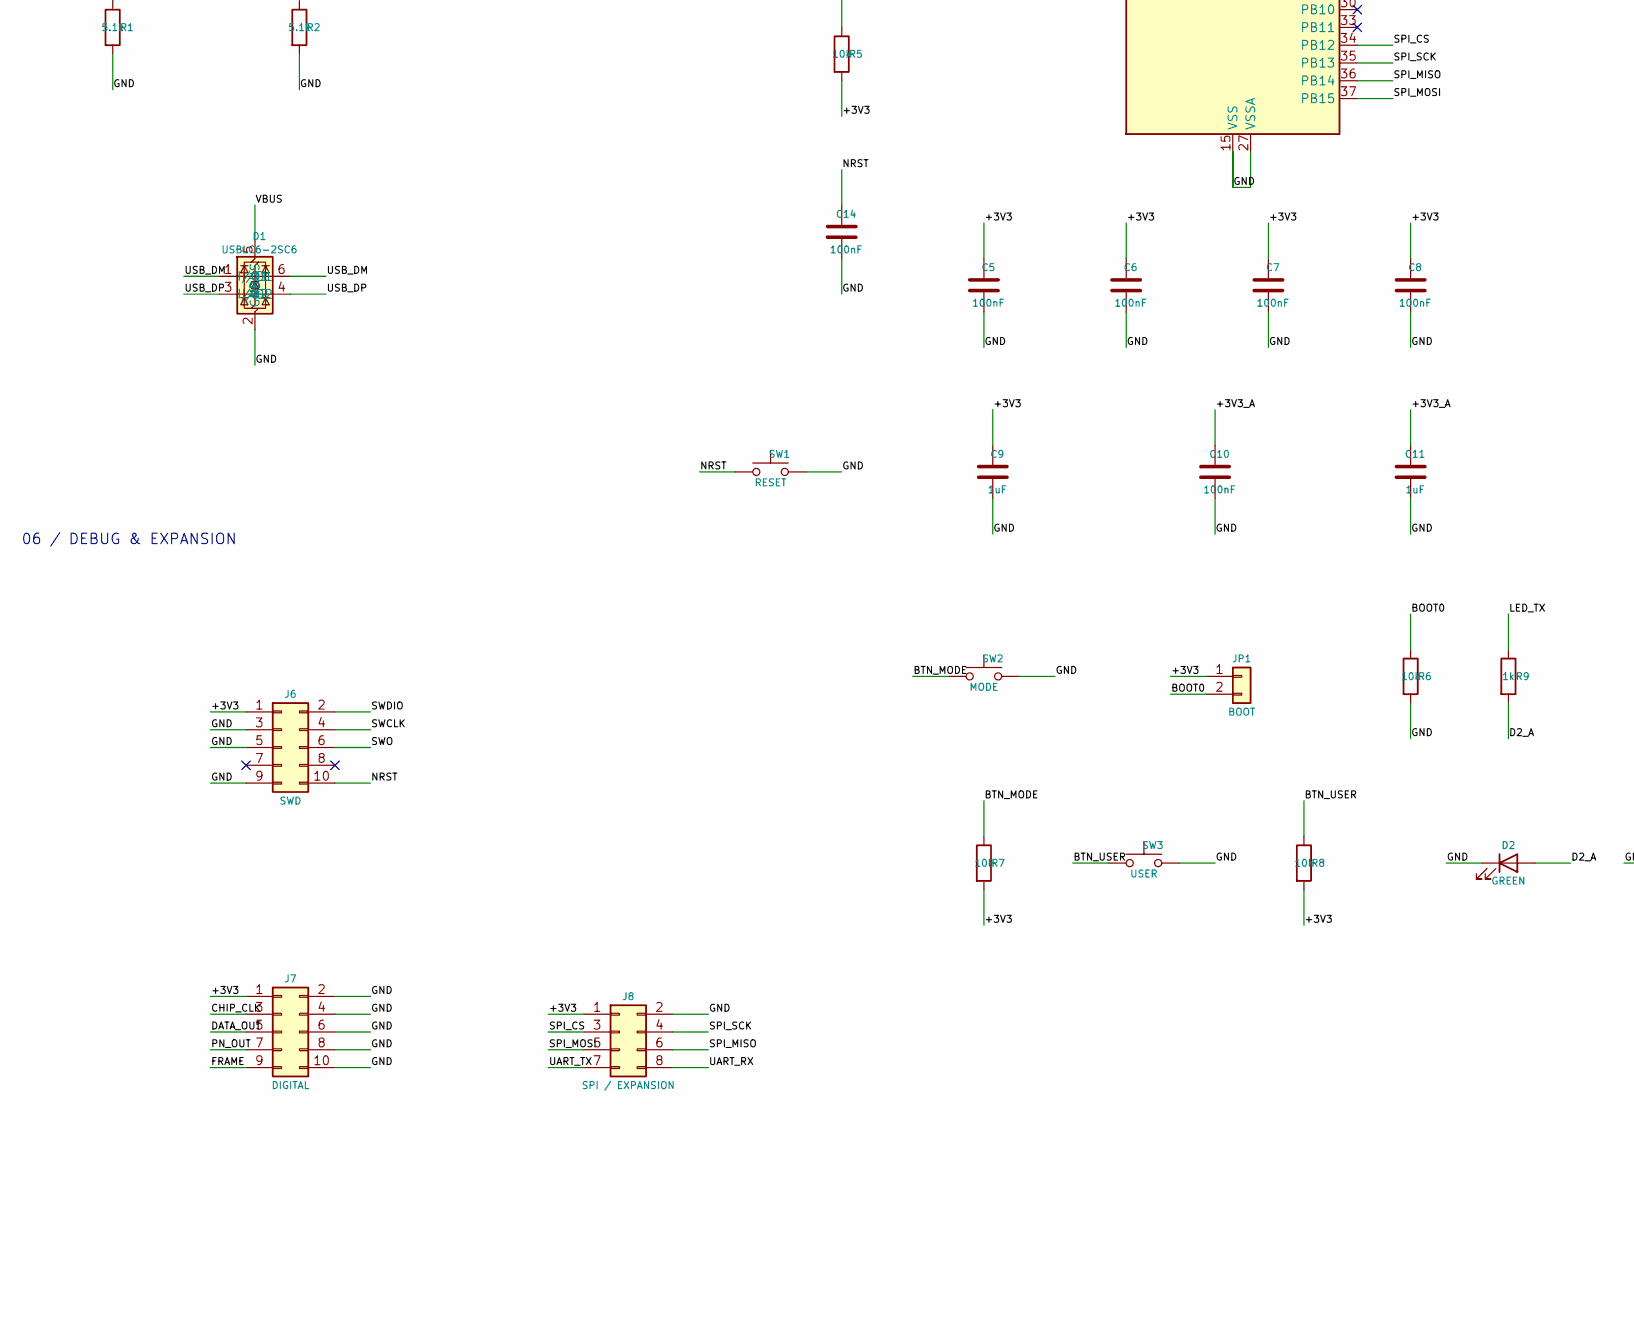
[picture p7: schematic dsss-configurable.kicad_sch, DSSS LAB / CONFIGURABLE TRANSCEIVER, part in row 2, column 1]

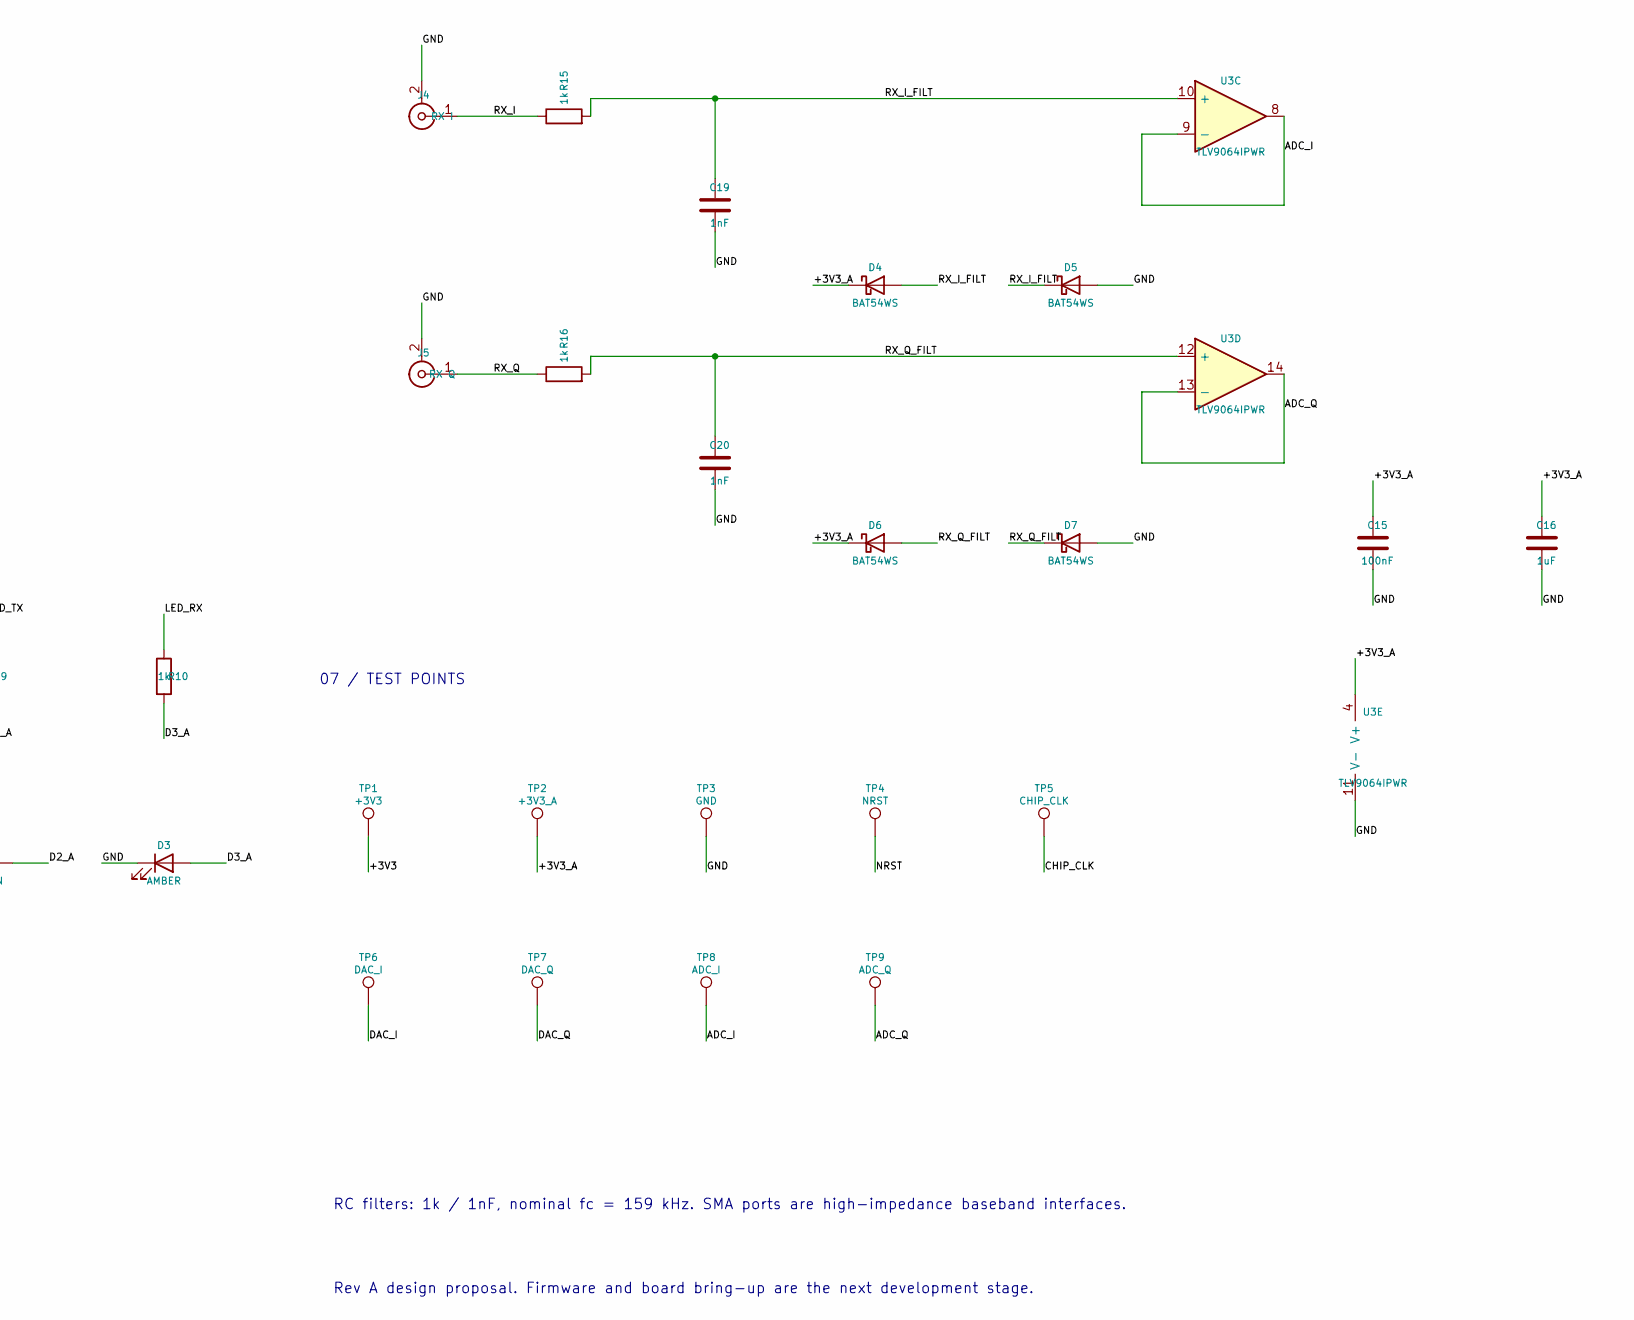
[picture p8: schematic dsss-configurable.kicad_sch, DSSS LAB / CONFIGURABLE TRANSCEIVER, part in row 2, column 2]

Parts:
C1, C2, C3: 4.7uF; C_0603_1608Metric
C4, C5, C6, C7, C8, C10, C14, C15: 100nF; C_0603_1608Metric
C9, C11, C16: 1uF; C_0603_1608Metric
C12, C13: 15pF; C_0603_1608Metric
C17, C18, C19, C20: 1nF; C_0603_1608Metric
D1: USBLC6-2SC6; SOT-23-6
D2: GREEN; LED_0603_1608Metric
D3: AMBER; LED_0603_1608Metric
D4, D5, D6, D7: BAT54WS; D_SOD-323
F1: 500mA PTC; Fuse_1206_3216Metric
FB1: 600R@100MHz; R_0603_1608Metric
J1: USB-C / CONTROL; USB_C_Receptacle_GCT_USB4105-xx-A_16P_TopMnt_Horizontal
J2: TX I; SMA_Amphenol_132291_Vertical
J3: TX Q; SMA_Amphenol_132291_Vertical
J4: RX I; SMA_Amphenol_132291_Vertical
J5: RX Q; SMA_Amphenol_132291_Vertical
J6: SWD; PinHeader_2x05_P1.27mm_Vertical
J7: DIGITAL; PinHeader_2x05_P2.54mm_Vertical
J8: SPI / EXPANSION; PinHeader_2x04_P2.54mm_Vertical
JP1: BOOT; PinHeader_1x02_P2.54mm_Vertical
R1, R2: 5.1k; R_0603_1608Metric
R3, R4: 22R; R_0603_1608Metric
R5, R6, R7, R8: 10k; R_0603_1608Metric
R9, R10, R11, R13, R15, R16: 1k; R_0603_1608Metric
R12, R14: 100R; R_0603_1608Metric
SW1: RESET; SW_SPST_TL3342
SW2: MODE; SW_SPST_TL3342
SW3: USER; SW_SPST_TL3342
TP1: +3V3; TestPoint_Pad_D1.5mm
TP2: +3V3_A; TestPoint_Pad_D1.5mm
TP3: GND; TestPoint_Pad_D1.5mm
TP4: NRST; TestPoint_Pad_D1.5mm
TP5: CHIP_CLK; TestPoint_Pad_D1.5mm
TP6: DAC_I; TestPoint_Pad_D1.5mm
TP7: DAC_Q; TestPoint_Pad_D1.5mm
TP8: ADC_I; TestPoint_Pad_D1.5mm
TP9: ADC_Q; TestPoint_Pad_D1.5mm
U1: STM32G474RET6; LQFP-64_10x10mm_P0.5mm
U2: AP2112K-3.3; SOT-23-5
U3: TLV9064IPWR; TSSOP-14_4.4x5mm_P0.65mm
Y1: 8MHz / CL 10pF; Crystal_SMD_3225-4Pin_3.2x2.5mm

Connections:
+3V3: C2.1, C5.1, C6.1, C7.1, C8.1, C9.1, FB1.1, J6.1, J7.1, J8.1, JP1.1, R5.2, R7.2, R8.2, TP1.1, U1.1 (VBAT), U1.16 (VDD), U1.32 (VDD), U1.48 (VDD), U1.64 (VDD), U2.5 (VOUT)
+3V3_A: C3.1, C4.1, C10.1, C11.1, C15.1, C16.1, D4.1 (K), D6.1 (K), FB1.2, TP2.1, U1.28 (VREF+), U1.29 (VDDA), U3.4 (V+)
+5V: C1.1, F1.2, U2.1 (VIN), U2.3 (EN)
ADC_I: TP8.1, U1.8 (PC0), U3.8, U3.9 (-)
ADC_Q: TP9.1, U1.9 (PC1), U3.13 (-), U3.14
BOOT0: JP1.2, R6.1, U1.61 (PB8)
BTN_MODE: R7.1, SW2.1, U1.2 (PC13)
BTN_USER: R8.1, SW3.1, U1.3 (PC14)
BUF_I: R12.1, U3.1, U3.2 (-)
BUF_Q: R14.1, U3.6 (-), U3.7
CC1: J1.A5 (CC1), R1.1
CC2: J1.B5 (CC2), R2.1
CHIP_CLK: J7.3, TP5.1, U1.42 (PA8)
D2_A: D2.2 (A), R9.2
D3_A: D3.2 (A), R10.2
DAC_I: R11.1, TP6.1, U1.18 (PA4)
DAC_Q: R13.1, TP7.1, U1.19 (PA5)
DATA_OUT: J7.5, U1.59 (PB6)
FRAME: J7.9, U1.38 (PC6)
GND: C1.2, C2.2, C3.2, C4.2, C5.2, C6.2, C7.2, C8.2, C9.2, C10.2, C11.2, C12.2, C13.2, C14.2, C15.2, C16.2, C17.2, C18.2, C19.2, C20.2, D1.2 (GND), D2.1 (K), D3.1 (K), D5.2 (A), D7.2 (A), J1.A1 (GND), J1.A12 (GND), J1.B1 (GND), J1.B12 (GND), J1.SH (SHIELD), J2.2 (Ext), J3.2 (Ext), J4.2 (Ext), J5.2 (Ext), J6.3, J6.5, J6.9, J7.2, J7.4, J7.6, J7.8, J7.10, J8.2, R1.2, R2.2, R6.2, SW1.2, SW2.2, SW3.2, TP3.1, U1.15 (VSS), U1.27 (VSSA), U1.31 (VSS), U1.47 (VSS), U1.63 (VSS), U2.2 (GND), U3.11 (V-), Y1.2 (G), Y1.4 (G)
HSE_IN: C12.1, U1.5 (PF0), Y1.1
HSE_OUT: C13.1, U1.6 (PF1), Y1.3
LED_RX: R10.1, U1.25 (PB1)
LED_TX: R9.1, U1.24 (PB0)
NRST: C14.1, J6.10, R5.1, SW1.1, TP4.1, U1.7 (PG10)
PN_OUT: J7.7, U1.60 (PB7)
RX_I: J4.1 (In), R15.1
RX_I_FILT: C19.1, D4.2 (A), D5.1 (K), R15.2, U3.10 (+)
RX_Q: J5.1 (In), R16.1
RX_Q_FILT: C20.1, D6.2 (A), D7.1 (K), R16.2, U3.12 (+)
SPI_CS: J8.3, U1.34 (PB12)
SPI_MISO: J8.6, U1.36 (PB14)
SPI_MOSI: J8.5, U1.37 (PB15)
SPI_SCK: J8.4, U1.35 (PB13)
SWCLK: J6.4, U1.50 (PA14)
SWDIO: J6.2, U1.49 (PA13)
SWO: J6.6, U1.56 (PB3)
TX_I: J2.1 (In), R12.2
TX_I_FILT: C17.1, R11.2, U3.3 (+)
TX_Q: J3.1 (In), R14.2
TX_Q_FILT: C18.1, R13.2, U3.5 (+)
UART_RX: J8.8, U1.17 (PA3)
UART_TX: J8.7, U1.14 (PA2)
USB_DM: D1.1 (I/O1), D1.6 (I/O1), J1.A7 (D-), J1.B7 (D-), R3.1
USB_DM_MCU: R3.2, U1.45 (PA11)
USB_DP: D1.3 (I/O2), D1.4 (I/O2), J1.A6 (D+), J1.B6 (D+), R4.1
USB_DP_MCU: R4.2, U1.46 (PA12)
VBUS: D1.5 (VBUS), F1.1, J1.A4 (VBUS), J1.A9 (VBUS), J1.B4 (VBUS), J1.B9 (VBUS)

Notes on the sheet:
01 / USB POWER & ANALOG SUPPLY
02 / USB DEVICE INTERFACE
03 / MCU, CLOCK & CONTROL
04 / DUAL DAC TRANSMIT PATH
05 / DUAL ADC RECEIVE PATH
06 / DEBUG & EXPANSION
07 / TEST POINTS
RC filters: 1k / 1nF, nominal fc = 159 kHz. SMA ports are high-impedance baseband interfaces.
Rev A design proposal. Firmware and board bring-up are the next development stage.

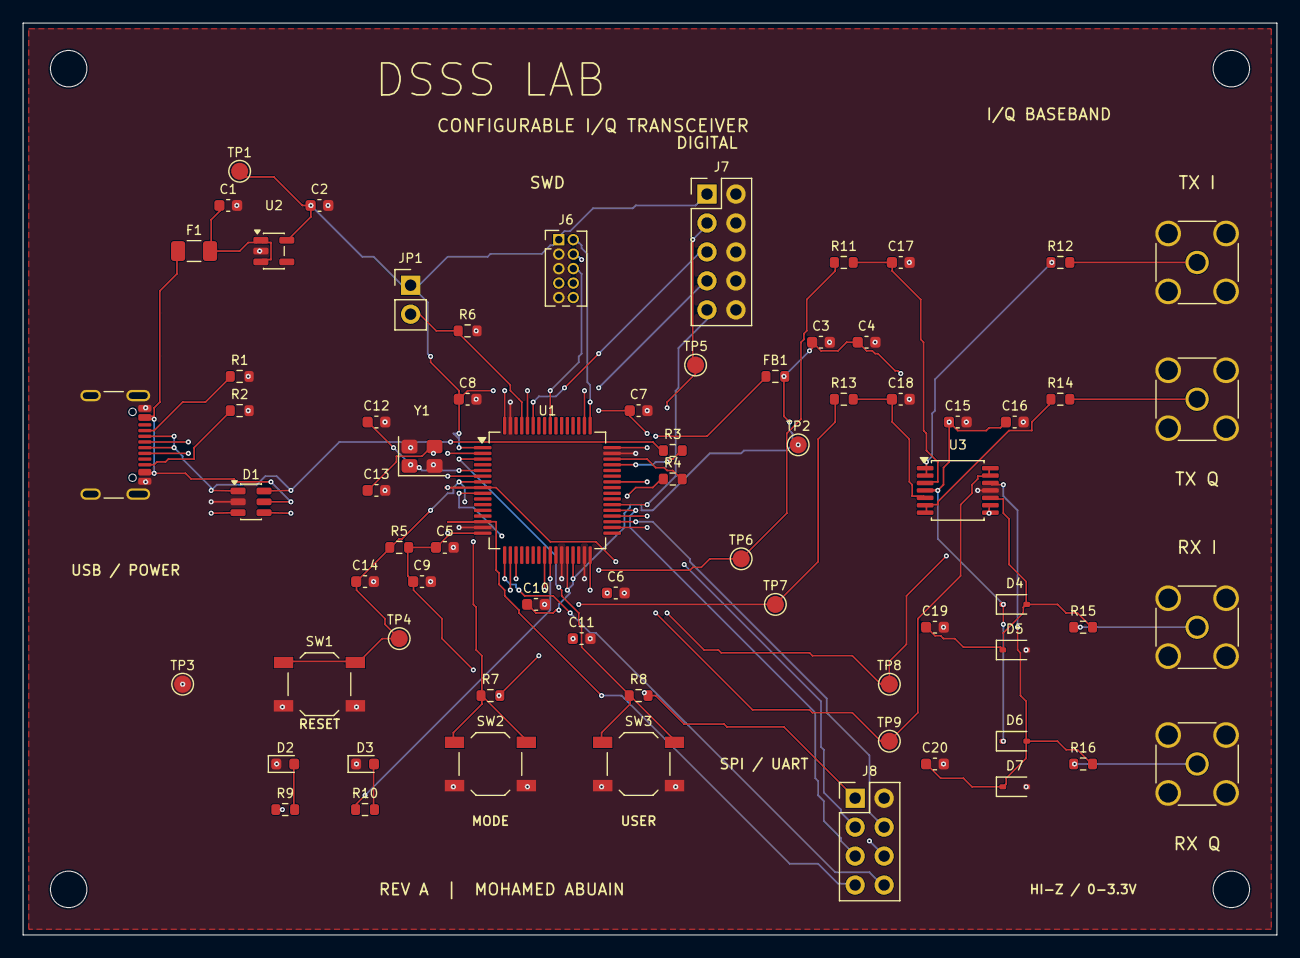
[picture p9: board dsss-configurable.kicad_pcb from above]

Board: 4 copper layers, 110.0 x 80.0 mm, 74 parts (0 on the bottom side), 48 nets.

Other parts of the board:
H1, H2, H3, H4: MountingHole_3.2mm_M3

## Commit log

2026-09-27 Refine project documentation and include QEX circuit reference
2026-09-27 Add configurable STM32 I/Q transceiver schematic and routed Rev A PCB
    [bom.csv, dsss-configurable.kicad_pcb, dsss-configurable.kicad_sch]
2026-09-27 Add multiuser CDMA receiver study and interactive explorer
    [cdma_near_far.csv]
